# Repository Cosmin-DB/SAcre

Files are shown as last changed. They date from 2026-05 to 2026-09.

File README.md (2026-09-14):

# SAcre / SmartFeedbackDevice

Diseño electrónico de un dispositivo portátil basado en ESP32.

- Autor: Cosmin Dobrescu
- Herramienta: KiCad 10
- Proyecto principal: `sacre.kicad_pro`
- Estado: esquema y PCB corregidos; revisión digital completada (2026-09-13).
  Pendientes: aprobación física final, preparación del pedido y pruebas del prototipo.

## Mecanismo de trabajo

1. Leer este archivo completo antes de continuar una revisión.
2. Usar este README como única fuente de verdad. Las hipótesis nuevas del
   asistente se mantienen únicamente en `REVISION_PROVISIONAL.md` hasta que el
   autor las acepte o descarte; no crear otros informes auxiliares.
3. Mantener un identificador estable para cada incidencia.
4. Tratar toda incidencia inicialmente como una hipótesis, no como un fallo
   confirmado.
5. Intentar refutarla contrastando esquemático, PCB, símbolo, huella, datasheet
   y, cuando exista, evidencia del prototipo.
6. Registrar únicamente:
   - `Hipótesis`: afirmación que se comprueba.
   - `Evidencia`: datos concretos que sostienen el dictamen.
   - `Acción`: cambio exacto, solo si procede.
   - `Cierre`: comprobación necesaria para darlo por válido.
7. Usar estos estados:
   `PENDIENTE → CONFIRMADO / DESCARTADO / CONDICIONAL → CORREGIDO → VALIDADO`.
8. Durante la verificación no modificar el diseño.
9. La preparación de PCB autorizada el 2026-09-13 ya se completó. El enrutado
   y ajuste físico quedan al autor; cualquier nueva modificación de PCB por
   el asistente requiere un alcance autorizado. Comparar antes/después y no
   alterar cobre, contorno, conectores o keepout fuera de ese alcance.
10. Registrar por separado en cada incidencia:
    - `[ ] Esquemático corregido`
    - `[ ] PCB corregida y revisada por el autor`
11. Corregir únicamente incidencias `CONFIRMADO`; no corregir las
    `CONDICIONAL` sin resolver antes su condición.
12. Marcar `VALIDADO` solo después de aplicar el criterio de cierre y las
    comprobaciones ERC/DRC pertinentes.
13. Mantener separadas las mejoras preventivas de los fallos demostrados.
14. Evitar duplicar información y conservar las entradas breves, verificables
    y comprensibles sin contexto externo.
15. No volver a listar como trabajo pendiente una corrección ya aplicada.
    Distinguir revisión digital, aprobación del autor y prueba física; los
    datos de versiones antiguas deben identificarse como históricos.

## Fuentes para la verificación

Los datasheets recopilados están en `documentation/datasheets/`; se conservan
también los documentos útiles que ya estaban en `documentation/` y `RV-8803/`.
`bom_jlcpb.csv` identifica las piezas del prototipo anterior: sirve para
investigar sus fallos, no para pedir la nueva placa. Para fabricar, generar
el BOM desde el diseño actual usando sus campos `LCSC Part #`; ni los BOM
históricos ni las tablas resumidas de este documento sustituyen esa exportación.

| Bloque | Referencias cubiertas | Estado |
| --- | --- | --- |
| MCU y RF | ESP32-PICO-D4, guía de hardware ESP32, AN012400C00R3200 | Completo |
| Pantalla y táctil | GDEY042T81-T02, SSD1683, FT6336U, AFC24-S06FIC-00, AFC24-S24FIA-00 | Completo |
| USB, sensores y mando | CP2104, conector USB-C, LIS3DH, RV-8803-C7, pulsador | Completo |
| Alimentación y protección | TLV62568, TP4054, FHD4020S-470MT, FTC252012S1R0MBCA, BAT54C, MBR0530, SP0503BAHTG | Completo |
| Transistores y motor | CJ2312, CJ3415, SI1308EDL, UMH3N, S8050 | Completo para los componentes montados |

Selección actual de referencias críticas (incluye las sustituciones del prototipo):

| Ref. | Pieza seleccionada | LCSC |
| --- | --- | --- |
| Q2 | R+O S8050 | C20069125 |
| U5 | JSMSEMI TP4054 | C5381776 |
| L1 | cjiang FHD4020S-470MT | C843300 |
| L3 | cjiang FTC252012S1R0MBCA | C5832370 |
| Q4 | TECH PUBLIC SI1308EDL | C7603347 |
| D1, D8, D9 | JSCJ MBR0530 | C77336 |
| D2–D4 | onsemi MBR0530T3G | C236079 |
| D5 | R+O BAT54C | C22466350 |

Los documentos de MCP73831 y LQH44PN quedan solo como comparación: no
describen los componentes seleccionados para la nueva fabricación.

Auditoría de campos de compra: **85 componentes, 39 códigos distintos** con
`LCSC Part #` idéntico en esquema y PCB, incluida R28=`C21190` como R11.
No se añaden alias duplicados: Fabrication Toolkit, instalado en este equipo,
lee ese campo y lo exporta junto a `Designator`, `Footprint`, `Quantity` y
`Value`. Sincronizar esquema y PCB antes de exportar; comprobar códigos y
orientaciones en la previsualización de JLCPCB, no sólo la detección automática.
Chequeo del exportador y propuestas no aplicadas de reducción de variedad:
`REVISION_PROVISIONAL.md`, sección «BOM y posiciones de montaje» (2026-09-14).
Fuentes: [atributos del exportador](https://github.com/bennymeg/Fabrication-Toolkit#attributes)
y [guía KiCad de JLCPCB](https://jlcpcb.com/help/article/how-to-generate-the-bom-and-centroid-file-from-kicad).

H1–H4, J5, J6 y TP1 son elementos de PCB, sin referencia de compra y excluidos
del BOM. M1 se compra por AliExpress: excluido del BOM y del archivo de
posiciones de montaje en esquema y PCB; su huella y conexiones se conservan.
Quedan por confirmar modelo, corriente de arranque y encaje del motor.

Preparación del pedido (2026-09-14): JLCPCB emparejó correctamente las 85
referencias con los 39 códigos previstos para **4 placas ensambladas**. U2,
ESP32-PICO-D4 `C193707`, está clasificado como `Standard Only`, por lo que el
pedido debe usar **Standard PCBA, cara superior**. La propuesta de sustituir
R23/R24 por valores ya presentes reduciría dos alimentadores, pero fue
descartada por el autor: se conservan 24 kΩ/47 kΩ y 39 códigos. En la
previsualización, el autor corrigió manualmente sólo la orientación de Y1;
comprobarla otra vez en cualquier pedido futuro.

Stock consultado en la biblioteca de montaje JLCPCB el 2026-09-13:
39 referencias con existencias. AE1 tenía 8 unidades, pero el autor dispone
de acopio propio; Y1 tenía 2 y se acepta omitir el RTC si falta. SW1 tenía
970 unidades, cantidad aceptada por el autor. Reconfirmar disponibilidad al
pedir: la consulta no reserva piezas ni el stock de LCSC garantiza montaje
inmediato en JLCPCB. Preparar el pedido teniendo en cuenta el acopio y las
omisiones acordadas; no se ha cambiado ningún campo DNP del diseño.

## Fallos observados en el prototipo

Las correcciones indicadas ya están aplicadas al esquema y a la PCB.
Las casillas de aprobación del autor y las pruebas físicas siguen abiertas;
no significan que falte repetir el enrutado. La evidencia del fallo describe
la primera placa fabricada, no la versión actual.

- [ ] `TOUCH-01` SDA y SCL intercambiadas en el FPC táctil.
  - [x] Esquemático corregido: J1.1=`SCL` y J1.2=`SDA`.
  - [ ] PCB corregida y revisada por el autor.
  - `Estado`: CORREGIDO EN ESQUEMA Y PCB; prueba del táctil pendiente.
  - `Cierre`: comprobar detección del FT6336U y niveles/flancos de ambas
    señales con el flex conectado.
- [ ] `TOUCH-02` Revisar holgura, orientación y salida del flex táctil.
- [ ] `MOTOR-01` Incompatibilidad entre el pinout de Q2 y su huella.
  - [x] Esquemático corregido: Q2 es el S8050 SOT-23 montado, B1/E2/C3
    (`C20069125`).
  - [ ] PCB corregida y revisada por el autor.
  - `Estado`: CORREGIDO EN ESQUEMA Y PCB; validación del motor pendiente.
- [x] `TOUCH-03` Pull-up de la interrupción táctil descartado.
  - `Estado`: DESCARTADO; `INT_TOUCH` puede permanecer en GPIO35.
  - `Evidencia`: el FT6336U declara `INT` como E/S CMOS y no prescribe un
    pull-up externo. Verificar por medida sólo si aparecen flancos inestables.
- [ ] `PWR-02` El USB provoca arranque y ciclos rápidos de encendido/apagado.
  - `Estado`: CORREGIDO EN ESQUEMA Y PCB; validación del encendido pendiente.
  - `Hipótesis`: en el diseño fabricado U3 queda alimentado directamente por
    `USB_VBUS` mientras U2 está apagado. `TXD` llega sin aislamiento a `U0RXD`
    y `DTR/RTS` cruzan
    también hacia `EN/GPIO0` mediante Q7; cualquiera de esas vías puede
    realimentar parcialmente el ESP32 y `+3V3`. Esa tensión puede activar
    IO25/Q6 y el latch. Al caer de nuevo la alimentación, el USB repite el
    proceso.
  - `Evidencia`: en el diseño fabricado U3 está configurado como bus-powered;
    `TXD` y `U0RXD` están unidos directamente. Q7 contiene resistencias de base
    internas de 4,7 kΩ,
    pero no aísla un dominio alimentado de otro apagado. IO25 controla la
    puerta de Q6 mediante R18, Q6 tiene un umbral de 0,45–1 V y R14 sólo lo
    descarga con 100 kΩ. R13/C18 forman una constante de 30 ms. L2 puede
    agravar la caída, pero no explica el disparo inicial desde USB.
  - `Decisión`: U3 queda self-powered físicamente. `VDD`, `VIO` y `REGIN` van
    a `+3V3`; R23/R24=24 kΩ/47 kΩ detectan `USB_VBUS` sin realimentación;
    C23=1 µF y C20=0,1 µF desacoplan U3. C17=1 µF mejora `EN`.
    R13/C18 permanecen en 300 kΩ/100 nF; no se añade supervisor ni histéresis.
    El firmware debe activar IO25 pronto y puede exigir mantener el pulsador
    durante la programación.
  - `Cierre`: al conectar USB con el latch apagado, observar `VSYS`, `+3V3`,
    puerta de Q6 y puerta de Q5. Si `+3V3` sube antes que `VSYS`, queda
    confirmada la realimentación desde U3; repetir aislando `TXD` o forzando
    la puerta de Q6 a GND.
  - `Fuentes`: [CP2104, figura 9](documentation/cp2104-1397921.pdf),
    [ESP32-PICO-D4](documentation/datasheets/ESP32-PICO-series.pdf),
    [CJ2312](documentation/datasheets/CJ2312.pdf) y
    [circuito de referencia](https://circuitcellar.com/resources/quickbits/soft-latching-power-circuits/).
  - [x] Esquemático corregido.
  - [ ] PCB corregida y revisada por el autor.
- [ ] `MCU-01` Desacoplo externo local insuficiente en U2.
  - `Estado`: CORREGIDO EN ESQUEMA Y PCB; validación con radio/táctil pendiente.
  - `Hipótesis`: U2 depende de condensadores de `+3V3` alejados y carece del
    par externo recomendado junto al encapsulado.
  - `Evidencia`: el ESP32-PICO-D4 une a `VDD33` los pines 1 `VDDA`, 3 y 4
    `VDDA3P3`, 19 `VDD3P3_RTC` y 37 `VDD3P3_CPU`; su referencia añade
    10 µF + 0,1 µF externos. En la PCB, C17 es de `EN`; C22 está junto al
    regulador y C3/C4 desacoplan el LIS3DH. El SiP incorpora desacoplo interno,
    pero no elimina ese par externo.
  - `Acción`: añadidos C26=10 µF y C27=0,1 µF entre `+3V3` y GND, colocados
    junto al grupo 1/3/4 de U2. Conexión corta y ancha a U2.3/4, con vía GND
    a unos 1 mm del centro de C27.2. Los
    pines 19 y 37 deben quedar unidos por un plano o recorrido de baja
    impedancia; no se prescriben condensadores adicionales junto a ellos
    porque el PICO-D4 ya integra 0,1 µF en ambos dominios.
  - `Cierre`: comprobar colocación y retornos en PCB y medir `+3V3` junto a U2
    con Bluetooth y táctil simultáneos, sin caída por debajo de 3,0 V ni
    brownout.
  - `Fuente`: [ESP32-PICO-D4, figuras 7 y 10](documentation/datasheets/ESP32-PICO-series.pdf).
  - [x] Esquemático corregido.
  - [ ] PCB corregida y revisada por el autor.

## Correcciones aplicadas por bloques

Esquemático sincronizado y PCB enrutada por el autor. Las tareas abiertas
de estos bloques son de firmware o validación física, salvo indicación expresa.

### 1. GPIO, reset táctil y RTC

- [x] `RES_TOUCH_CTRL` en GPIO4; GPIO16 queda sin conexión externa, reservado
  para la flash interna del PICO-D4. JP1 eliminado. R11 y R28, ambas de 1 kΩ
  (`C21190`), están en paralelo: 500 Ω efectivos entre GPIO4 y RSTN.
  Mejora preventiva del nivel bajo sin añadir otra referencia al BOM;
  omitiendo R28 se recupera 1 kΩ. Ambas están previstas para montar.
  C25=10 µF a GND y D8 descarga el nodo al caer `+3V3`. Firmware:
  GPIO4 en drenador abierto, nivel bajo ≥60 ms, liberar sin conducir nivel alto
  y esperar ≥300 ms antes de usar I²C.
- [ ] Validar en prototipo el reset: nivel bajo calculado ≈0,47 V a 3,3 V
  con R11/R28, por debajo de 0,3·IOVCC. Mejora aplicada en esquema y PCB;
  prueba física pendiente. La secuencia de firmware no cambia.
- [x] `ACC_INT2` movida de GPIO12 a GPIO34; se conservan ambas interrupciones.
- [x] `RTC_INT` permanece en GPIO27 con R22=10 kΩ a `+3V3`.
- [x] `RTC_EVI` desconectada de GPIO15, R21=100 kΩ a `VBAT_RAW` y TP1.
- [x] Etiqueta huérfana `GPO` eliminada; GPIO32 queda libre.
- [x] Y1 alimentado directamente por `VBAT_RAW`, sin regulador añadido;
  C2=0,1 µF como desacoplo local.

- [x] Esquemático corregido.
- [ ] PCB corregida y revisada por el autor.

La aprobación final de encaje mecánico corresponde al autor.

### 2. USB, latch, C18 y EN

- [x] U3 alimentado desde `+3V3`; `USB_VBUS` detectado mediante
  R23/R24=24 kΩ/47 kΩ.
- [x] C23=1 µF y C20=0,1 µF locales; C24=4,7 µF/25 V en `VPP`.
- [x] C17=1 µF con R12=10 kΩ en `EN`.
- [x] R13/C18 conservados en 300 kΩ/100 nF; supervisor e histéresis descartados.
- [ ] Firmware integrado: activar IO25 pronto; mantener pulsado durante programación si
  el reset hace caer el latch. Requisito anotado junto al circuito del latch.
  Autosostén implementado en los ocho miniproyectos de `firmware/`;
  integración y prueba física pendientes.
- [x] Esquemático corregido.
- [ ] PCB corregida y revisada por el autor.

### 3. Regulador, ESP32, pantalla y motor

- [x] Pull-ups I²C R7/R8 cambiados de 10 kΩ a 5,1 kΩ para dar margen a
  400 kHz reutilizando el valor existente en el BOM.
- [x] ADP2108 sustituido por U6=`TLV62568DBVR` (`C163219`): buck de 1 A,
  salida nominal de 3,318 V con R26/R27=453 kΩ/100 kΩ. C31/C32=10 µF.
  Se elige por margen de corriente, disponibilidad y coste; el menor consumo
  en reposo y la salida fija del ADP2108 no justifican mantenerlo aquí.
- [x] `L3` fijada como
  [`FTC252012S1R0MBCA`](https://jlcpcb.com/partdetail/FTC252012S1R0MBCA/C5832370),
  LCSC `C5832370`: 1 µH, 4 A, Isat 5,6 A y DCR 35 mΩ. Huella de esquema
  `L_Changjiang_FTC252012S`; `C1042` queda solo como pieza histórica no válida.
  El campo `LCSC Part #` permite su selección automática en el BOM de JLCPCB.
- [x] C26=10 µF y C27=0,1 µF añadidos junto a U2 en el esquemático.
- [x] C26/C27 colocados y retornos revisados; C30 dispone de vía GND local.
- [x] Booster SSD1683 corregido en esquema: L1=47 µH, R10=2,2 Ω;
  C6 permanece en 4,7 µF/25 V; C8/C16 eliminados.
- [x] `L1` fijada como
  [`FHD4020S-470MT`](https://jlcpcb.com/partdetail/FHD4020S-470MT/C843300),
  LCSC `C843300`: 47 µH, 660 mA, Isat 1,3 A y DCR 950 mΩ. Huella de esquema
  `L_Changjiang_FNR4020S`. El campo `LCSC Part #` permite su selección
  automática en el BOM de JLCPCB.
- [x] Booster actualizado y revisado en PCB; Q4.2–R10.2 reducido a 2,34 mm.
  R9=1 MΩ entre GDR y GND, según la aplicación específica del panel.
- [x] Q2 corregido en esquema al pinout real B1/E2/C3 del S8050
  `C20069125`; se conservan R2=1 kΩ y D1.
- [x] Motor pasado de `+3V3` a `VSYS` mediante D9=MBR0530; `VMOTOR` alimenta
  M1, D1 y C1=0,1 µF. R25=100 kΩ mantiene la base de Q2 descargada. PWM
  opcional; encendido/apagado directo condicionado al motor indicado abajo.
- [x] Etapa dimensionada provisionalmente para el motor candidato: 3 V,
  rango 2,5–4 V y 70 mA nominales, suponiendo 90 mA de arranque. Confirmar
  este último dato en el motor comprado; no equivale a validación física.
- [ ] Confirmar modelo comprado, dimensiones/huella y corriente de arranque:
  no dar por corregido a 90 mA el dato ambiguo de 901 mA del anuncio.

### 4. Cargador y batería

- [x] C29=1 µF entre U5.4 `VDD` y GND y C28=10 µF entre U5.3 `VBAT` y
  GND añadidos y colocados junto a U5; retornos locales revisados en PCB.
- [x] R19=5,1 kΩ: unos 196 mA para la batería prevista de 600–700 mAh;
  reutiliza el mismo valor que R16/R17.
- [x] Protección integrada en la batería confirmada por el autor.
- [ ] Firmware integrado: habilitar la medida con GPIO26, leer `ADC_BATT`, deshabilitarla
  y apagar antes de ciclos repetidos de brownout. Requisito anotado en esquema;
  lectura implementada en `firmware/07_bateria`; umbral pendiente de medida.
- [x] Power-path descartado. U5 carga directamente `VBAT_RAW`; carga normal con
  el equipo apagado y encendido temporal permitido para programación.
- [x] Mantener TP4054 `C5381776`: LCSC/JLCPCB lo especifican a 4,2 V. La tabla
  ambigua del datasheet se conserva como cautela de validación, no como fallo
  que obligue a cambiar U5.

### 5. PCB y mecánica

Estado: **ENRUTADA Y REVISADA DIGITALMENTE** (2026-09-13), 93 componentes,
incluida R28 añadida y enrutada por el autor.

- [x] Sincronización, colocación y enrutado de las correcciones; revisión de
  desacoplos, retornos, GPIO y pinout de Q2. DRC sin conexiones pendientes.
- [x] Pista RF ajustada, J3 corregido a NPTH y vías separadas de la ranura.
- [x] Q4–R10 compactado; pasta bajo U2 conservada por decisión del autor.
  D6 no se mueve por la faja; U6 y SW1 se conservan según lo acordado.
- [ ] Comprobar físicamente flex de J1/pantalla, batería, motor y carcasa.
- [ ] Aprobar la PCB y preparar el pedido; ensayar el nuevo prototipo.

Histórico, no estado actual: `ae7a2bc` antes de preparar la PCB;
`92a95f1` colocación provisional; `0903610` enrutado y revisión final.
Las vistas [anterior](documentation/pcb_preparacion/antes.png),
[provisional](documentation/pcb_preparacion/despues.png) y de
[colocación](documentation/pcb_preparacion/colocacion.png) documentan sólo
la preparación inicial; no sirven como referencia de fabricación actual.

## Fabricación y cierre

### Configuración de fabricación — 2026-09-14

Enrutado completado por el autor y revisión digital final realizada.
La configuración de fabricación no cambia la geometría del circuito.

- Pedido objetivo: FR-4 estándar TG135, **4 capas, 1 mm nominal**, cobre
  exterior **1 oz** e interior **0,5 oz**, verde, serigrafía blanca, HASL con
  plomo y fresado normal. Sin prestaciones especiales añadidas.
- Montaje objetivo: **4 unidades, Standard PCBA, sólo cara superior**. U2
  `C193707` impide Economic PCBA. Confirmar el archivo de producción antes de
  fabricar; AE1 y Y1 se seleccionaron desde `My Parts` en el emparejamiento.
- Apilado: **JLC04101H-7628**. La consulta pública de JLCPCB para esos
  parámetros devuelve esta estructura tanto en «No requirement» como al
  seleccionarla explícitamente, con `fixedFee=0`, `coefficient=0` y fabricación
  rápida habilitada. Confirmar precio final en el pedido; no se ha comprado nada.
- KiCad conserva estos parámetros también en las variables de texto del
  proyecto. Elegir el apilado explícito en el pedido para evitar ambigüedad.

| Capa | Espesor configurado | Material / εr de referencia |
| --- | --- | --- |
| F.Mask / B.Mask | 0,0152 mm cada una | Verde / 3,8 |
| F.Cu / B.Cu | 0,035 mm cada una | Cobre exterior 1 oz |
| Dieléctrico 1 / 3 | 0,2104 mm cada uno | FR4 7628 / 4,4 |
| In1.Cu / In2.Cu | 0,0152 mm cada una | Cobre interior 0,5 oz, tras procesado |
| Dieléctrico 2 | 0,5000 mm | Núcleo FR4 / 4,6 nominal |

La estructura publicada suma 1,0212 mm sin máscara; con la máscara modelada,
KiCad muestra **1,0516 mm**. Se pide **1,0 mm nominal**, tolerancia estándar
±10 %. No ajustar artificialmente los dieléctricos para que la suma dé 1,000.

**Límite del modelo RF:** εr son referencias publicadas, no caracterización
del lote TG135. La calculadora actual de JLC usa NP-155F para 4–8 capas y
40,64 µm de cobre exterior, frente a los 35 µm de su tabla de apilado. El
cálculo de la pista RF indicado abajo utiliza el modelo de fabricación de
JLC; no se ha cambiado a TG155 ni simulado la antena completa. `tanδ=0,02`
se conserva como valor orientativo, no como dato confirmado del laminado.

DRC configurado: pista/separación absolutas ≥0,10 mm, cobre–borde ≥0,20 mm,
taladro de vía ≥0,20 mm, diámetro ≥0,40 mm y anular ≥0,05 mm. La regla de
`sacre.kicad_dru` exige diámetro ≥0,45 mm si el taladro es <0,30 mm para
evitar recargo por vías pequeñas. Se mantienen las separaciones de red de
0,15 mm y vías preferidas de 0,50/0,30 mm.
Apertura de máscara–cobre ajeno ≥0,09 mm; texto ≥1 mm y trazo ≥0,15 mm.
No se han cambiado las aperturas de máscara ni las exclusiones existentes.
Los límites específicos de ranuras, PTH y procesos no quedan todos cubiertos
por estas reglas globales: ver las condiciones de fabricación en
`REVISION_PROVISIONAL.md`.

**Resultado:** 0 conexiones pendientes, 0 diferencias con el esquema;
0 infracciones no excluidas y 18 exclusiones previas tras corregir J3 y
adaptar el límite de las vías pequeñas. Los tres errores de
cobre–ranura y los dos avisos de serigrafía fueron corregidos por el autor.
Límites reaplicados con KiCad cerrado y DRC repetido tras detectar que un
guardado posterior había restaurado las restricciones antiguas del proyecto.
U2.49: el autor conserva las ventanas de pasta y las 16 vías recolocadas.
«Plugged» no garantiza el sellado de vías dentro del pad; se acepta esta
limitación sin añadir relleno epoxi/cobre. Calidad de soldadura pendiente
de validar; no es una recolocación o modificación de pasta pendiente.

Fuentes: [apilados JLCPCB](https://jlcpcb.com/impedance),
[capacidades](https://jlcpcb.com/capabilities/pcb-capabilities),
[modelo de cálculo](https://jlcpcb.com/help/article/user-guide-to-the-jlcpcb-impedance-calculator)
y [tratamiento de vías](https://jlcpcb.com/help/article/pcb-via-covering).

### Pista RF — ajuste autorizado el 2026-09-13 (`RV-11`)

- `/ANT_RF`: ancho **0,26 mm** en sus tres segmentos y dos arcos; recorrido,
  huella de antena, meandro y máscara sin cambios. Zonas rellenadas; separación
  lateral a GND ≈0,1505 mm y plano In1 continuo bajo la pista externa.
- Modelo JLC `CoatedCoplanarWaveguideWithLowerGnd1B`: H=0,2104 mm, εr=4,4,
  cobre acabado=40,64 µm, ancho superior 12,7 µm menor que el inferior;
  máscara εr=3,8, 25,4 µm sobre sustrato y 15,24 µm sobre cobre. Son los
  parámetros actuales del servicio, no todos coinciden con su página de ayuda.
- Resultado nominal con hueco lateral de 0,15 mm: **50,15 Ω** para 0,26 mm,
  frente a 44,87 Ω para el ancho anterior de 0,3341 mm. La aproximación previa
  sin máscara de 50,8 Ω queda sustituida por este contraste más completo.
- Este cálculo no valida la impedancia del lote TG135 ni la adaptación/alcance
  de la antena completa. Recalcular si cambian apilado, cobre, máscara, ancho,
  separación a masa o plano de referencia. Recordatorio junto a AE1 en
  `Cmts.User`, fuera del contorno; no forma parte de la serigrafía.
- [ ] PCB revisada visualmente por el autor; validación RF física pendiente.
- Fuente: [calculadora JLCPCB](https://jlcpcb.com/pcb-impedance-calculator).

### Checklist de cierre

- Revisión final de PCB (2026-09-13): 0 conexiones pendientes, 0 diferencias
  con el esquema y 0 infracciones no excluidas tras ajustar las reglas de vía;
  se mantienen 18 exclusiones previas. Q4–R10 ya corregido; pasta de U2 conservada por
  decisión del autor. Gerber/taladros revisados en `tmp/final-review-fab/`,
  no publicados como fabricación definitiva. Resultado y límites en
  `REVISION_PROVISIONAL.md`, «Cierre de revisión sobre el guardado actual».
- `RV-15`: agujeros de posicionamiento de J3 corregidos a NPTH de 0,70 mm
  en PCB y biblioteca; posiciones y anclajes soldados intactos. DRC sin
  infracciones nuevas por este cambio; revisión visual del autor pendiente.

Las siguientes casillas son el cierre humano o experimental, no correcciones
eléctricas obligatorias abiertas:

- [ ] `PWR-01` Medir alimentación, carga y encendido/apagado sin bucles.
- [ ] `USB-01` Probar enumeración y programación, incluido el autosostén.
- [ ] `MCU-02` Probar arranque/reset y coexistencia de táctil y Bluetooth.
- [ ] `DISP-01` Probar refresco y tensiones auxiliares de la pantalla.
- [ ] `SENS-01` Probar sensores/RTC y calibrar el umbral de batería baja.
- [ ] `RF-01` Validar alcance de radio; el cálculo de pista ya está realizado.
- [ ] `PCB-01` Aprobación visual final del autor; revisión digital completada.
- [ ] `MECH-01` Confirmar encaje, alturas, flex y accesibilidad.
- [ ] `FAB-01` Aprobar exclusiones DRC y avisos ERC, comprobar BOM/posiciones
  y stock del pedido, regenerar/revisar el paquete definitivo y confirmar CAM.
  ERC: 122 desajustes de símbolos y aviso de AE1.2, conectado a GND;
  no se declara limpio ni se actualizan bibliotecas a ciegas.

## Uso

Pruebas independientes para el hardware actual: [firmware/README.md](firmware/README.md).
Ocho proyectos PlatformIO, uno por periférico/función, con autosostén del latch
común. Incluyen mapa GPIO y criterios de prueba; validación física pendiente.

Abrir `sacre.kicad_pro`. Las librerías, huellas y modelos 3D del diseño están
incluidos en el repositorio; el estado de los datasheets figura arriba.

Cualquier exportación local en `production/` debe considerarse desactualizada
hasta completar `FAB-01`.

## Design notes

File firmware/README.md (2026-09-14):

# Pruebas independientes de SAcre

Autor: Cosmin Dobrescu. Destino: ESP32-PICO-D4, esquema/PCB de septiembre
de 2026. Cada carpeta es un proyecto PlatformIO que sustituye al anterior
al grabarlo. No hay una aplicación que combine los periféricos.

`common/board.h` concentra los GPIO, autosostén y apagado; `common/i2c_io.h`
contiene únicamente acceso a registros. Conservar `common/` junto a los
proyectos. Para integrarlos después, reutilizar sus rutinas de inicialización
y lectura, manteniendo un único arranque del latch y del bus I²C.

## Compilar y cargar

Instalar PlatformIO Core o la extensión PlatformIO de VS Code. Abrir la
carpeta de la prueba, o ejecutar desde la raíz del repositorio:

```text
pio run -d firmware/01_latch
pio run -d firmware/01_latch -t upload
pio device monitor -b 115200
```

Cambiar `01_latch` por la prueba elegida. Si hay varios puertos, añadir
`--upload-port COMx` al comando de carga y `-p COMx` al monitor.
Los comandos son letras/números ASCII; Intro es opcional.

Usar batería conectada. Mantener SW1 pulsado durante carga/reset y hasta
el arranque del programa; el USB no sustituye al pulsador de encendido.
En todas las pruebas, `x` apaga: soltar SW1 para que pueda cortar el latch.
Una operación en curso (por ejemplo, refrescar pantalla) termina antes de
atender el comando. Abrir el monitor puede perder el primer mensaje;
las pruebas de lectura siguen mostrando su estado periódicamente.

## Qué probar y qué observar

| Proyecto | Operación | Resultado esperado |
| --- | --- | --- |
| `01_latch` | Soltar SW1 después de arrancar; `x` apaga. `b` habilita lectura del botón; soltar, pulsar 4 s y soltar. | Sigue encendida sin pulsar; contador continuo, sin reinicios; apagado efectivo. |
| `02_pantalla` | `p` patrón, `w` blanco, `n` negro; ≥5 s entre refrescos. | Marco/texto/cuadrícula completos, blanco/negro uniformes. Imagen retenida al apagar. |
| `03_tactil` | Tocar, arrastrar y usar dos dedos; `r` repite reset. | Lecturas 0–2 puntos, coordenadas cambiantes, regreso a 0 al soltar; INT/flancos observables. |
| `04_motor` | `1`, `2`, `3`: pulso de 200 ms a 25 %, 50 %, 100 %; `0` para. | Vibra y se detiene; reposo de 2 s entre órdenes, sin reinicios. A PWM bajo puede no arrancar. |
| `05_acelerometro` | Girar y mover la placa. | Identidad `0x33`; en reposo módulo de aceleración ≈1000 mg; signos/ejes cambian; INT1 datos listos, INT2 al superar ≈1,28 g en algún eje. |
| `06_rtc` | `t` inicializa, `a` alarma al próximo minuto, `c` cancela/limpia. Apagar y volver a encender sin `t`. | Segundos avanzan y hora se conserva con batería; alarma da AF=1 e INT=0, `c` los libera. |
| `07_bateria` | Lectura automática cada 2 s; comparar con multímetro. | Tensión próxima a la batería; divisor se deshabilita tras cada lectura. |
| `08_bluetooth` | Cliente BLE: conectar a `SAcre-BLE-test`, leer/suscribirse y reconectar. | Contador ASCII creciente por lectura/notificación, reconexión y sin reinicios. |

BLE: servicio `b0d80001-6c3a-4d2e-a947-5ac000000001`, característica
`b0d80002-6c3a-4d2e-a947-5ac000000001`. Sin emparejamiento obligatorio;
usar un explorador GATT, no sólo la lista de dispositivos del sistema.

## GPIO contrastados con esquema y PCB

Son números de **GPIO**, no de patilla del encapsulado. Los 17 valores de
`common/board.h` se contrastan con redes de U2 y pads reales de la PCB.

| Función / red | GPIO |
| --- | --- |
| Autosostén `PWR_BTN` | 25 |
| Motor `Vibration_PWM` | 13 |
| Batería `VBAT_SENSE_EN` / `ADC_BATT` | 26 / 33 (ADC1) |
| I²C `SDA` / `SCL` | 21 / 22 |
| Táctil `RES_TOUCH_CTRL` / `INT_TOUCH` | 4 / 35 |
| Acelerómetro `ACC_INT1` / `ACC_INT2` | 14 / 34 |
| RTC `RTC_INT` | 27 |
| Pantalla `SS` / `DC` / `RES` | 5 / 10 / 9 |
| Pantalla `BUSY` / `SCK` / `MOSI` | 19 / 18 / 23 |

GPIO34/35 se usan sólo como entradas, sin pull-up interno. GPIO16 y las
señales internas de flash no se usan. GPIO9/10 sí están disponibles en el
PICO-D4 con esta configuración DIO. `RTC_EVI` no está conectado al ESP32.

## Decisiones que hay que conservar al integrar

- **Latch:** GPIO25 HIGH es la primera acción de `setup()`. Los proyectos de
  periféricos mantienen HIGH continuamente. Sólo `01_latch`, tras `b`, usa
  ventanas de entrada de 200 µs para leer SW1 a través de D5/R18; dependen
  del circuito R13/C18 (~30 ms) y necesitan validación física. No se hereda
  automáticamente esta lectura del botón en el resto de pruebas.
- **Táctil:** GPIO4 open-drain LOW 70 ms, liberar y esperar 350 ms, conforme
  a R11||R28=500 Ω y C25=10 µF. Nunca conducir HIGH en push-pull. Se lee el
  FT6336U en `0x38`, 100 kHz, con transferencias acotadas y errores explícitos.
  Las coordenadas son nativas; no se presupone orientación del flex/pantalla.
- **Acelerómetro:** SA0/SDO tiene pull-up interno según el datasheet, por lo
  que se espera `0x19` aunque no tenga conexión externa. Se comprueban
  `0x18/0x19` y WHO_AM_I antes de escribir. Modo ±2 g, 10 Hz, 12 bits,
  BDU; INT1 indica datos listos e INT2 movimiento por umbral.
- **RTC opcional:** si falta, el programa informa y permite apagar.
  Arrancar no cambia la hora. `t` reinicializa la configuración escribible,
  incluido offset=0, a fecha/hora de **compilación**, no a la hora actual del
  PC al cargar. `V2F`/RESET impiden presentar la hora como válida.
  Cada escritura termina con lectura por la errata I²C del RV-8803;
  no se generan pulsos de recuperación indiscriminados. `a` dedica INT a la
  alarma; se deja AF activo hasta `c`, y puede repetirse al día siguiente
  si se deja armada. La batería mantiene esos registros al apagar el ESP32.
- **Pantalla:** driver específico GDEY042T81/SSD1683, sólo refresco completo,
  hibernación al terminar. El SPI no identifica el panel: fin del driver
  no demuestra imagen correcta; comprobar BUSY y aspecto físico.
- **Motor:** apagado inicial y pulsos sólo por orden. PWM no limita el pico
  de arranque ni protege un motor incompatible. Modelo/corriente del motor
  siguen condicionados a lo anotado en el README de hardware.
- **Batería:** R5/R6=10 kΩ/10 kΩ, factor 2; ADC en mV y atenuación 11 dB.
  Ajustar `CALIBRATION` con multímetro. No inventar porcentaje ni umbral de
  apagado: queda para la integración, tras medir la batería y la caída bajo carga.

## Verificación y fuentes

Verificación 2026-09-14: ocho proyectos compilados y enlazados para `pico32`;
17 GPIO contrastados automáticamente con netlist del esquema y pads de la PCB.
Sin avisos en el código propio; dos avisos de variables sin uso en drivers
ajenos al panel elegido dentro de GxEPD2. No probado en placa:
compilación y contraste de GPIO no validan el funcionamiento físico
ni la coexistencia de periféricos. La integración y pruebas combinadas quedan
para una fase posterior.

Base fijada: PlatformIO espressif32 6.1.0 / Arduino-ESP32 2.0.7, `pico32`,
flash 4 MB DIO. Pantalla: GxEPD2 1.6.4, Adafruit GFX 1.11.11 y BusIO 1.16.1.
El resto usa Arduino/Wire/BLE incluidos en esa plataforma.

Referencias: [diseño y decisiones actuales](../README.md),
[LIS3DH](../documentation/lis3dh_datasheet.pdf),
[RTC: mapa, alarmas e inicialización](../RV-8803/RV-8803-C7_App-Manual.pdf),
[errata RTC](../documentation/datasheets/RV-8803-C7-errata.pdf),
[FT6336U](../documentation/datasheets/FT6336U.pdf),
[panel](../documentation/datasheets/GDEY042T81-T02.pdf),
[driver GxEPD2](https://github.com/ZinggJM/GxEPD2/tree/1.6.4),
[formato de registros táctiles](https://github.com/bitbank2/FT6236G/blob/master/src/FT6236G.cpp).
Se toma como referencia funcional el proyecto local de mayo/junio de 2026
`260527-095526-pico32`; sus pines antiguos no son la referencia de esta versión.

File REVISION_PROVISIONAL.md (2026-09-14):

# Revisión provisional independiente

**Autor:** Cosmin Dobrescu
**Última actualización:** 2026-09-14
**Estado:** revisión digital completada; pruebas del prototipo pendientes.
El README mantiene el checklist vigente y las decisiones aceptadas.

No se repiten aquí los cinco fallos ya anotados en el esquemático.

## BOM y posiciones de montaje — 2026-09-14

Revisión con Fabrication Toolkit instalado, traducción automática activada.
Campos corregidos y documentados; las propuestas siguientes **no se han
aplicado**. No se han cambiado valores, huellas, giros ni pistas en esta pasada.

### BOM-01 — Reducir variedad sin modificar el enrutado

- **Estado: DESCARTADA PARA ESTA REVISIÓN por el autor (2026-09-14).** Se
  evaluó cambiar R23 de 24 kΩ a
  5,1 kΩ (`C23186`) y R24 de 47 kΩ a 10 kΩ (`C25804`), ambas 0603, 1 %.
  Reutiliza dos referencias existentes y elimina `C23352` y `C25819`:
  **39 → 37 códigos**, manteniendo la cantidad de componentes.
- **Evidencia:** el divisor de detección USB pasa de 3,3099 V a 3,3113 V
  con entrada de 5 V. A 5,25 V y tolerancias de 1 % en el peor sentido,
  pasa de 3,4988 V a 3,5002 V, por debajo del límite de 3,6 V con U3 apagado.
  No amplía el rango USB admitido ni protege frente a sobretensiones.
- **Coste eléctrico:** consumo del divisor de 70 a 331 µA mientras hay USB
  (+0,261 mA desde USB, no desde la batería). La resistencia equivalente
  baja de 15,89 a 3,38 kΩ; no empeora el error por fugas de entrada.
- **Justificación:** cálculo propio sobre la figura 9, nota 5 del
  [CP2104](https://www.silabs.com/documents/public/data-sheets/cp2104.pdf),
  que permite un divisor funcionalmente equivalente; 5,1 kΩ/10 kΩ no es
  una pareja prescrita por el fabricante. No se promete ahorro económico
  concreto: la mejora comprobada es reducir variedad.
- **Decisión:** conservar R23=24 kΩ (`C23352`) y R24=47 kΩ (`C25819`). El
  ahorro observado era de unos 2,6 EUR por pedido Standard, insuficiente para
  cambiar una PCB ya terminada. Para diseños futuros, priorizar piezas Basic,
  compatibilidad Economic y reutilización de referencias desde el inicio.

Otros resultados del chequeo:

- **Sólo agrupación:** el exportador produce 41 líneas para 39 códigos porque
  C17/C23/C29 dicen `1uF` y sus equivalentes `1uF/50V`; C30 dice `100nF` y
  sus equivalentes `0.1uF`. Uniformar esos textos reduciría a 39 líneas,
  pero no elimina ninguna referencia de compra; ya comparten código LCSC.
- **Diodos: no unificar de oficio.** D1/D8/D9 y D2–D4 usan dos MBR0530 de
  fabricantes distintos. D9 se eligió para reducir la tensión del motor:
  no basta compartir encapsulado y tensión nominal para asegurar la misma
  caída. Cambiar sólo D1/D8 no reduce variedad porque D9 conserva su código.
- **C18:** su 100 nF es 0402, frente a los demás 0603. Unificarlo exige
  cambiar huella y revisar espacio/pistas; no compensa tocar esta PCB sólo
  por ese motivo. No se propone alterar temporizaciones, feedback o
  componentes de potencia para reutilizar valores a costa de su función.

### FAB-02 — Orientaciones y centros del archivo de posiciones

- **Estado: exportador comprobado y previsualización revisada por el autor.**
  Las 85 referencias del BOM tienen posición, todas en cara superior y sin
  duplicados. El CPL incluye además H1–H4, J5/J6 y TP1, excluidos del BOM:
  son siete entradas sin pieza a montar, no siete componentes sin código.
  M1 queda fuera de ambos archivos por compra/montaje independiente.
- El exportador usa el centro de la caja de pads y el origen auxiliar,
  invirtiendo Y para el CPL. Respecto al ancla de KiCad desplaza el centro
  calculado de J3 0,175 mm a la izquierda, SW1 0,075 mm a la izquierda y
  AE1 0,025 mm a la izquierda/0,030 mm arriba. No demuestra descentrado:
  comprobar el cuerpo sobre sus pads, no igualar coordenadas por intuición.
- Se contrastaron las geometrías numeradas de 26 componentes con bibliotecas
  EasyEDA descargadas por el MCP. **Su cero angular no certifica el cero de
  montaje de JLCPCB.** Q4 no tiene regla SOT-323 en el exportador; Y1 usa
  una huella personalizada; D6 recibe la regla genérica SOT-143 y U2/U3 la
  QFN. Son comprobaciones prioritarias, no giros erróneos demostrados.

Referencia rápida para la previsualización, mirando la PCB por arriba con
la misma orientación que KiCad (X crece a la derecha, Y hacia abajo):

| Pieza | Ángulo CPL actual | Referencia física que debe coincidir con la PCB |
| --- | --- | --- |
| Q4 | 270° | Gate/pad 1 arriba a la derecha; drenador/pad 3 abajo |
| D6 | 270° | Común GND/pad 1 abajo a la izquierda |
| U2 | 270° | Pad 1 en el extremo inferior del lateral derecho |
| U3 | 90° | Pad 1 en el extremo superior del lateral izquierdo |
| Y1, si se monta | 180° | Pad 1 abajo a la derecha |
| D7 | 180° | Cátodo a la derecha, en el pad 1 de KiCad |

En D7 se descartó una falsa alarma de 180° al comprobar el símbolo:
EasyEDA llama **2** al cátodo y KiCad **1**. Comparar sólo los números
habría confundido una convención distinta con un fallo de polaridad.
J1/J2/J3 y SW1 coinciden en orientación de pads con sus huellas importadas;
revisar también la boca del USB y las entradas de los flex en el visor.
No se pudo obtener la huella EasyEDA de AE1: contrastar con su plano y el
componente del acopio al preparar su montaje.

**Resultado de la previsualización (2026-09-14):** el autor encontró correcto
el posicionamiento del resto de componentes y corrigió manualmente únicamente
la orientación de Y1. El ángulo de corrección no quedó registrado, por lo que
todavía no se puede fijar un `FT Rotation Offset` fiable para automatizar Y1
en otro pedido. No se ha girado su huella física ni fijado offsets nuevos.
En futuros pedidos, revisar de nuevo la previsualización con el código exacto
de cada pieza antes de aceptar el montaje.
Los ángulos de esta tabla dependen de mantener activada la traducción
automática de este exportador. No son una tabla para el exportador nativo.
Fuentes: [atributos de Fabrication Toolkit](https://github.com/bennymeg/Fabrication-Toolkit#attributes)
y [guía de corrección de posiciones de JLCPCB](https://github.com/JLCPCB/JLCPCB-SMT-Assembly-Components-orientation-fix).

## Evidencia del prototipo

### OBS-01 — Pantalla funcional; táctil y Bluetooth no coexistían correctamente

**Relato del autor (2026-07-28)**

- El conjunto usado era la pantalla táctil de 4,2 pulgadas declarada en el
  diseño; la pantalla funcionaba.
- El táctil y Bluetooth no funcionaban correctamente al usarlos
  simultáneamente. Falta precisar si ambos funcionaban por separado.

**Separación de bloques**

- La tinta electrónica `GDEY042T81-T02` usa `SSD1683`, conector J2 de 24 pines
  y SPI. El booster sólo interviene al generar las tensiones de refresco.
- El táctil `FT6336U` usa el conector J1 de 6 pines, bus I²C y `+3V3`. Su
  consumo activo típico es 4,32 mA.
- Bluetooth es interno al ESP32 y no comparte los GPIO del I²C. No aparece un
  conflicto directo de pines entre ambas funciones.
- Táctil, ESP32 y booster reciben energía de la misma red `+3V3`.

**Fuentes:** [esquemático](sacre.kicad_sch), [panel](documentation/datasheets/GDEY042T81-T02.pdf), [FT6336U](documentation/datasheets/FT6336U.pdf), [ESP32-PICO](documentation/datasheets/ESP32-PICO-series.pdf).

**Interpretación provisional**

- `TOUCH-01` —SDA y SCL intercambiadas en el FPC— explica un fallo directo del
  táctil, pero no un fallo propio de Bluetooth.
- `RV-05` es ahora la causa lógica más fuerte del táctil si JP1 estaba cerrado:
  su reset comparte por error el `FLASH_CS` interno del ESP32.
- `RV-01` es una causa común plausible: la actividad de radio eleva la demanda
  del ESP32 y una caída de `+3V3` puede reiniciar o bloquear tanto el MCU como
  el FT6336U.
- `RV-02` sólo explicaría la coincidencia si se estaba refrescando la pantalla:
  el booster toma pulsos de corriente de `+3V3`.
- Siguen abiertas causas de firmware, concurrencia y desacoplo local del ESP32.

**Comprobación necesaria**

- [ ] Registrar qué funcionaba por separado: táctil, Bluetooth y refresco.
- [ ] Repetir una matriz táctil activo/inactivo × Bluetooth activo/inactivo,
      sin refrescar la pantalla.
- [ ] Repetir durante un refresco y medir mínimo/rizado de `+3V3`.
- [ ] Registrar brownouts, resets, errores I²C y desconexiones Bluetooth.

## Antecedentes del prototipo y correcciones RV-01–RV-10

Las descripciones de fallos siguientes corresponden al diseño anterior.
Las correcciones indicadas en esquema ya se trasladaron a la PCB y se
revisaron digitalmente; las comprobaciones físicas no se dan por superadas.
RV-08 es una decisión aceptada, no una propuesta de rediseño pendiente.

### RV-01 — L2 no es apta para el regulador de 3,3 V

**Confianza:** muy alta · **Impacto posible:** crítico

- El BOM fabricado monta en L2 `C1042`, identificado como `SDFL2012Q1R0KTF`.
- Su datasheet especifica `Ir = 50 mA` y `DCR = 0,4 Ω`.
- U4 es un ADP2108 de hasta 600 mA. Su datasheet exige que la corriente DC admisible de la bobina sea mayor que la corriente de pico; sus referencias de 1 µH parten de 800 mA.
- L2 alimenta toda la red `+3V3`, incluido el ESP32. Es una incompatibilidad objetiva aunque la placa llegue a arrancar.
- Espressif especifica una fuente capaz de entregar al menos 0,5 A al
  ESP32-PICO. La corriente nominal de L2 es diez veces menor incluso antes de
  sumar pantalla, táctil, sensores y motor.

**Implicaciones**

- `50 mA` no es un corte: L2 puede conducir más corriente, pero fuera de su
  especificación puede perder inductancia, calentarse y elevar el rizado.
- Los síntomas esperables son brownouts o resets del ESP32, fallos de radio,
  periféricos inestables y comportamiento dependiente de batería, temperatura
  o unidad fabricada.
- Es una explicación plausible para la parte Bluetooth de `OBS-01`, no una
  causalidad demostrada.

**Corrección aplicada en el esquemático**

- El conjunto U4/L2 fue sustituido por U6=`TLV62568DBVR` y
  L3=`FTC252012S1R0MBCA`, LCSC `C5832370`: 1 µH, 4 A, Isat 5,6 A y
  DCR 35 mΩ, huella `L_Changjiang_FTC252012S`. Aplicado también en PCB.

**Fuentes:** [BOM fabricado](bom_jlcpb.csv), [L2 C1042, pág. 4](documentation/datasheets/SDFL2012Q1R0KTF-C1042.pdf), [ADP2108, pág. 13](documentation/datasheets/ADP2108.pdf), [ESP32-PICO, tabla 17](documentation/datasheets/ESP32-PICO-series.pdf).

**Comprobación en la placa**

- [ ] Confirmar que la unidad ensayada corresponde al BOM con `C1042`.
- [ ] Registrar mínimo y rizado de `+3V3` durante arranque, radio activa y refresco de pantalla.
- [ ] Decisión: confirmar / descartar / condicionar.

### RV-02 — Booster de la pantalla configurado como UC, pero el panel usa SSD1683

**Confianza:** muy alta sobre la incompatibilidad; causalidad no demostrada · **Impacto posible:** alto, crítico si impide el refresco

- El diseño y el BOM usan `L1 = 10 µH` y `R10 = 0,47 Ω`.
- El panel declarado `GDEY042T81-T02` usa controlador `SSD1683`.
- La guía vigente de Good Display para DESPI-C02 asigna `10 µH + 0,47 Ω` a controladores UC y `47 µH + 2,2 Ω` a controladores SSD. Advierte que una selección incorrecta puede impedir el refresco.
- El esquema oficial DESPI-C02 V1.0 de 2018 usa una bobina fija de 10 µH y
  permite seleccionar `0,47 Ω` o `3 Ω`. La placa conserva precisamente la
  rama de `0,47 Ω`; éste es el origen más probable del valor.
- El circuito de aplicación del SSD1683 confirma `47 µH + 2,2 Ω`. La
  documentación posterior aclara que los valores antiguos no son universales.

**Funcionamiento e implicaciones**

- El SSD1683 controla Q4 mediante `GDR`. L1 almacena energía y los diodos y
  condensadores generan `PREVGH`, `PREVGL` y `VCOM`.
- `RESE` mide sobre R10 la corriente de Q4. Para una misma tensión de control,
  `0,47 Ω` permite unas 4,7 veces más corriente que `2,2 Ω`; con 10 µH la
  corriente también crece unas 4,7 veces más rápido que con 47 µH.
- Esto no implica 4,7 veces más tensión de salida: implica un lazo de corriente
  distinto y mayor esfuerzo durante el arranque del booster.
- Puede causar ausencia o degradación del refresco, poco contraste, ghosting,
  calentamiento y picos sobre `+3V3`. También puede funcionar por tolerancias y
  regulación interna, como ocurrió en el prototipo, sin validar sus márgenes.
- El funcionamiento observado de la pantalla reduce la probabilidad de un
  fallo inmediato, pero no refuta la incompatibilidad ni descarta estrés.

**Alcance revisado**

- Q4 `SI1308EDL` y los Schottky `MBR0530` coinciden con la recomendación
  actual.
- El mapeo completo del FPC confirma su orientación inversa respecto a J2.
  El circuito específico del panel GDEY042T81-T02 resuelve la diferencia entre
  el circuito genérico del SSD1683 y esta aplicación:
  - C6=4,7 µF/25 V coincide con el circuito de referencia del panel y se
    conserva; el valor genérico de 1 µF no prevalece sobre la aplicación
    específica.
  - C8 cargaba con 1 µF J2.21, correspondiente al pin 4 del panel, declarado
    `NC / keep open`.
  - C16 cargaba con 1 µF J2.6, correspondiente al pin 19 `VPP`, declarado
    `FOR TEST` y dejado abierto en el circuito de referencia del panel.
- El táctil FT6336U es un bloque I²C independiente. El booster no explica por sí
  solo su fallo salvo por una caída compartida de `+3V3`.

**Corrección aplicada en el esquemático**

- `L1 = 47 µH` y `R10 = 2,2 Ω`. L1 queda como `FHD4020S-470MT`, LCSC
  `C843300`: 660 mA, Isat 1,3 A y DCR 950 mΩ, con huella
  `L_Changjiang_FNR4020S` en el esquema.
- C6 se conserva en 4,7 µF/25 V; C8 y C16 se eliminan.
- Aplicado también en PCB; el retorno Q4–R10 está compactado (`RV-13`).

**Fuentes:** [BOM fabricado](bom_jlcpb.csv), [panel GDEY042T81-T02](documentation/datasheets/GDEY042T81-T02.pdf), [SSD1683, circuito de aplicación pág. 46](documentation/datasheets/SSD1683.pdf), [producto oficial: IC SSD1683](https://www.good-display.com/product/473.html), [DESPI-C02 V1.0 de 2018](https://v4.cecdn.yun300.cn/100001_1909185148/DESPI-C02_SCH%20V1.0.pdf), [guía oficial DESPI-C02, secciones 3.1 y 4.1–4.4](https://www.good-display.com/companyfile/29.html).

**Comprobación en la placa**

- [ ] Confirmar referencia/revisión del panel realmente probado.
- [ ] Precisar si «funcionaba» incluía refrescos completos y repetibles.
- [ ] Medir `PREVGH`, `PREVGL`, `VCOM` y `+3V3` durante un refresco.
- [ ] Decisión: confirmar / descartar / condicionar.

### RV-03 — Falta el pull-up de `RTC_INT`

**Confianza:** muy alta · **Impacto posible:** alarma/temporizador RTC inoperante o inestable

- `RTC_INT` conecta únicamente `Y1.6` con `U2.IO27`; no hay resistencia de pull-up.
- La salida `INT` del RV-8803-C7 es open-drain y el fabricante indica expresamente que requiere pull-up.
- Un pull-up interno habilitado por firmware puede ocultar el fallo durante algunas pruebas, pero no existe durante reset ni está garantizado por el hardware.

**Corrección aplicada en el esquemático**

- R22=10 kΩ entre `RTC_INT` y `+3V3`; Y1.6 permanece en GPIO27.

**Fuentes:** [RV-8803-C7](documentation/datasheets/RV-8803-C7-datasheet.pdf), [manual de aplicación oficial, pág. 64](https://www.microcrystal.com/fileadmin/Media/Products/RTC/App.Manual/RV-8803-C7_App-Manual.pdf).

**Comprobación en la placa**

- [ ] Medir `RTC_INT` en reposo con el GPIO sin pull-up interno.
- [ ] Provocar una alarma/temporizador y comprobar nivel alto estable y flanco bajo.
- [ ] Decisión: confirmar / descartar / condicionar.

### RV-04 — Falta desacoplo en la salida interna del CP2104

**Confianza:** muy alta · **Impacto posible:** enumeración USB o UART intermitente

- Los pines `VDD` y `VIO` de U3 están unidos entre sí, pero esa red no llega a ningún condensador.
- `REGIN/VBUS` sí tiene C20; no sustituye el desacoplo de `VDD/VIO`.
- El circuito bus-powered del fabricante coloca `1–5 µF` y `0,1 µF` entre `VDD` y GND.

**Implicaciones**

- Aunque no se use para alimentar circuitos externos, `VDD` es la salida del
  regulador interno que alimenta al propio CP2104; `VIO` fija su alimentación
  de E/S.
- La omisión puede producir rizado, resets del CP2104, enumeración USB
  intermitente o programación UART poco fiable. No implica un fallo seguro.

**Corrección aplicada en el esquemático**

- U3 queda alimentado desde `+3V3`; C23=1 µF y C20=0,1 µF son sus desacoplos
  locales. `USB_VBUS` se detecta mediante R23/R24 sin alimentar U3.

**Fuente:** [CP2104, figura 8, pág. 17](documentation/cp2104-1397921.pdf).

**Comprobación en la placa**

- [ ] Medir U3 pin 6 (`VDD`) al conectar USB y durante enumeración/tráfico.
- [ ] Registrar fallos de enumeración, resets o rizado.
- [ ] Decisión: confirmar / descartar / condicionar.

### RV-05 — El reset táctil está conectado a `FLASH_CS` interno

**Confianza:** muy alta · **Impacto posible:** crítico

- `U2.IO16`, pin físico 25 del ESP32-PICO-D4, no es un GPIO disponible:
  está conectado internamente a `FLASH_CS`.
- Esa señal sale como `RES_TOUCH` hasta JP1. Con JP1 cerrado, comparte el reset
  del FT6336U y su pull-up R11 de 10 kΩ. La actividad de la flash puede resetear
  el táctil y éste carga una señal interna crítica del ESP32.
- Con JP1 abierto no existe esa carga directa: R11 mantiene alto el reset del
  táctil. Aun así, el FT6336U no recibe su secuencia recomendada de reset bajo
  durante el encendido y queda un stub de PCB conectado a `FLASH_CS`.
- Es una explicación fuerte de `OBS-01` únicamente si la placa ensayada tenía
  JP1 cerrado.

**Corrección aplicada en el esquemático**

- JP1 y la conexión a IO16 se eliminan. `RES_TOUCH_CTRL` pasa a GPIO4 mediante
  R11=1 kΩ, C25=10 µF y D8; el firmware lo maneja en drenador abierto.
  Mejora posterior aplicada por el autor: R28=1 kΩ en paralelo con R11
  reduce la resistencia efectiva a 500 Ω y aumenta el margen del nivel bajo.

**Fuentes:** [ESP32-PICO-D4, tabla de pines](documentation/datasheets/ESP32-PICO-series.pdf), [FT6336U](documentation/datasheets/FT6336U.pdf).

**Dato pendiente**

- [ ] Confirmar si JP1 estaba soldado/cerrado en la unidad probada.
- [ ] Cierre: verificar en esquema y PCB que IO16 queda sin red, pista ni
      componente externo.

### RV-06 — `ACC_INT2` puede forzar el strap de 1,8 V de la flash

**Confianza:** muy alta sobre la conexión · **Impacto condicionado:** crítico

- `LIS3DH.INT2` llega a `GPIO12/MTDI` del ESP32.
- El ESP32 muestrea GPIO12 en cada reset: bajo selecciona 3,3 V para
  `VDD_SDIO`; alto selecciona 1,8 V. La flash interna del PICO-D4 trabaja a
  3,3 V.
- El LIS3DH arranca con INT2 push-pull a nivel bajo, por lo que un encendido en
  frío puede funcionar. Si el firmware deja INT2 alto y se reinicia sólo el
  ESP32 sin cortar `+3V3`, el sensor conserva ese estado durante el muestreo y
  puede provocar brownout o impedir el arranque.

**Corrección aplicada en el esquemático**

- `ACC_INT2` pasa a GPIO34, entrada sin función de strap.
- Cierre: comprobar arranque en frío y reset sólo de `EN` con INT2 activo.

**Fuentes:** [LIS3DH](documentation/lis3dh_datasheet.pdf), [guía de hardware ESP32](documentation/esp32_hardware_design_guidelines_en.pdf).

### RV-07 — Faltan los condensadores locales del TP4054

**Confianza:** muy alta · **Impacto posible:** carga inestable

- La aplicación típica del componente exacto pide 1 µF en su entrada de
  alimentación y 10 µF en la salida de batería, ambos locales a U5. En el
  símbolo del esquema son `VDD` y `VBAT`. Ninguno está presente.
- C2 es 0,1 µF sobre `VBAT_RAW` para el RTC; no sustituye los 10 µF locales de
  U5. C20 y C23 desacoplan `+3V3` en el CP2104, no `USB_VBUS`.

**Corrección aplicada en el esquemático**

- C29=1 µF entre U5.4 (`VDD`) y GND y C28=10 µF entre U5.3 (`VBAT`) y
  GND, colocados junto a U5 con retornos locales revisados en PCB.
- Cierre: comprobar estabilidad en U5.4 y U5.3 durante conexión y carga.

**Fuente:** [TP4054 JSMSEMI, aplicación típica](documentation/datasheets/TP4054-JSMSEMI-C5381776.pdf).

### RV-08 — El cargador no separa la batería de la carga del sistema

**Confianza:** muy alta sobre la topología · **Impacto condicionado:** alto

- U5 conecta `BAT` directamente a `VBAT_RAW`; no existe power-path ni reparto
  de carga.
- Si el equipo permanece encendido mientras carga, el TP4054 mide conjuntamente
  batería y consumo del sistema. La terminación puede retrasarse o no producirse
  y la batería puede aportar los picos que excedan la corriente del cargador.
- R19 se cambia de 10 kΩ a 5,1 kΩ: programa unos 196 mA para la batería prevista
  de 600–700 mAh y reutiliza el valor de R16/R17. La terminación ocurre
  alrededor de C/10, por lo que una carga activa superior a unos 20 mA puede
  impedirla.
- La batería incorpora protección propia, confirmado por el autor.
- El datasheet del TP4054 contiene una tabla ambigua con un límite de 4,28 V y
  grados A/B poco claros. Sin embargo, LCSC y JLCPCB identifican el componente
  exacto `C5381776` como 4,2 V. Se mantiene U5; medir la tensión final forma
  parte de la validación, no de una corrección del esquema.

**Decisión cerrada**

- No añadir power-path. U5 permanece conectado directamente a `VBAT_RAW`.
- Especificar carga normal con el equipo apagado. Mantenerlo encendido
  temporalmente para programar es admisible, aunque no garantiza terminación
  de carga mientras exista consumo.
- Cierre: validar terminación y corriente real con el sistema apagado y, si se
  permite, encendido.

### RV-09 — `RTC_EVI` queda sin nivel definido con el MCU apagado

**Confianza:** muy alta · **Impacto posible:** eventos espurios del RTC

- `Y1.EVI` conecta únicamente con GPIO15. El RV-8803 permanece alimentado desde
  `VBAT_RAW`, mientras el ESP32 y sus polarizaciones desaparecen al apagar el
  latch.
- El fabricante indica que EVI no debe quedar flotante.

**Corrección aplicada en el esquemático**

- `RTC_EVI` se desconecta de GPIO15 y queda inactiva mediante R21=100 kΩ a
  `VBAT_RAW`, con TP1 para un posible uso futuro.
- Cierre: medir un nivel definido en EVI con el latch encendido y apagado.

**Fuente:** [manual RV-8803-C7](RV-8803/RV-8803-C7_App-Manual.pdf).

### RV-10 — El RC de `EN` conserva la recomendación antigua de 100 nF

**Confianza:** muy alta sobre la desviación · **Impacto posible:** arranque menos robusto

- R3 = 10 kΩ y C17 = 100 nF forman el reset de encendido del ESP32.
- La guía vigente de Espressif recomienda 10 kΩ + 1 µF para mejorar la
  estabilidad de encendido.

**Corrección aplicada en el esquemático**

- C17=1 µF con R12=10 kΩ. El arranque será algo más lento y puede exigir
  mantener el pulsador durante más tiempo; no sustituye la corrección de
  `PWR-02`.
- Cierre: comprobar subida limpia de `EN`, arranque manual y reset de
  programación.

**Fuente:** [guía de hardware ESP32](documentation/esp32_hardware_design_guidelines_en.pdf).

## Condiciones abiertas, no clasificadas como fallo

- Pull-ups I²C R7/R8=5,1 kΩ ya aplicados. Usar 100 kHz hasta validar los
  flancos del conjunto PCB/flex; no se garantiza 400 kHz sólo por ese valor.
- **Regulador: selección cerrada.** U6=`TLV62568DBVR` de 1 A sustituye al
  ADP2108; L3 y C31/C32 son los componentes actuales. El motor toma energía
  de `VSYS`. Presupuesto y márgenes en `AUDITORIA_COMPONENTES.md`.
- Con batería baja, verificar el apagado por firmware antes de perder el
  margen de alimentación del ESP32; la protección de batería no sustituye
  ese umbral, pendiente de calibración.
- La medida de batería en ADC1 es válida; añadir 100 nF local sería una mejora
  de filtrado, no un fallo demostrado.
- `MOTOR-01`: Q2 ya está corregido al pinout B1/E2/C3 del S8050 montado
  (`C20069125`). El motor toma energía de `VSYS` mediante D9=MBR0530;
  C1=0,1 µF y R25=100 kΩ. PCB aplicada; dimensionado condicionado al candidato
  de 70 mA nominales y 90 mA de arranque. Quedan referencia de compra,
  corriente real y comprobación mecánica; no se considera ensayado.

## Comprobaciones descartadas

- **D5/BAT54C:** el pin común 3 va al pulsador; D5.1 sí permite descargar la puerta de Q5. La topología de encendido es coherente.
- **LIS3DH:** símbolo, desacoplo, `CS` y `SDO/SA0` son coherentes; `ACC_INT2`
  ya está corregida de GPIO12 a GPIO34 según `RV-06`.
- **ESP32-PICO-D4:** `SD2/GPIO9` y `SD3/GPIO10` no están ocupados por la flash interna de esta variante. El condensador de `VDD_SDIO` mostrado en el esquema interno forma parte del SiP; no se cuenta como componente externo ausente.
- **CP2104:** el pad expuesto central es GND opcional según el fabricante; que
  esté sin conectar no constituye un fallo. El pinout y la función de Q7 son
  correctos.
- **USB-C y RF:** CC1/CC2, protección ESD, pares USB, adaptación integrada del
  PICO-D4 y keepout de antena no muestran otro fallo eléctrico evidente.

## Revisión de enrutado — 2026-09-13

### Cierre de revisión sobre el guardado actual (2026-09-13)

Último contraste de documentación, netlist actual y referencias de fabricante:
sin incompatibilidad grave nueva detectada. DRC repetido con relleno de zonas
en memoria: 0 infracciones activas, 18 exclusiones, 0 conexiones pendientes y
0 diferencias con el esquema. La mejora posterior R11/R28 ya está aplicada
por el autor en esquema y PCB; el asistente completa sólo el campo de compra
de R28 y excluye M1 de BOM/posiciones, sin tocar geometría ni conexiones.
85 componentes tienen código de compra coincidente en esquema y PCB.
Persisten las condiciones del motor y las pruebas del reset descritas en
`AUDITORIA_COMPONENTES.md`; no se considera superada ninguna prueba física.
Corregida en README la selección de D2–D4 a `C236079` y separada del BOM histórico.

Referencia histórica de cobre revisado, anterior a R28 y a la nota RF en `Cmts.User`:
SHA256 `e97267a49af78ba223983d335d8b887f7e7fd721cb2c1a0c7f3eb2a174cb04b4`.
La nota documental no cambia cobre, componentes, taladros ni máscaras.

- **DRC:** 0 conexiones pendientes, 0 diferencias con el esquema y 0 infracciones
  no excluidas tras el ajuste autorizado de reglas. Taladro mínimo de 0,20 mm;
  `sacre.kicad_dru` exige diámetro exterior ≥0,45 mm si el taladro es <0,30 mm.
  Quedan 18 avisos excluidos previos, no 22 tras corregir J3. Prueba aislada:
  admite 0,20/0,45 y 0,30/0,40 mm; rechaza 0,20/0,40 y taladro de 0,15 mm.
  Geometría de PCB intacta.
- **Fabricación:** las 159 vías son pasantes: 135 de 0,30/0,50 mm, 20 de
  0,40/0,80 mm y 4 de 0,20/0,45 mm (taladro/diámetro exterior). Ninguna
  incumple las combinaciones sin recargo por vía pequeña publicadas por JLC.
- **RV-13:** Q4.2–R10.2 corregido por el autor: 2,34 mm a 0,25 mm, sin vías,
  frente a 15,94 mm. R10 retorna al cobre local GND. No queda propuesta de
  recolocación; validar el booster en el prototipo.
- **RV-17:** ahora hay 16 vías bajo U2.49; ningún taladro se solapa con las
  nueve ventanas de pasta. Margen mínimo de las cuatro interiores: 0,020–0,034 mm.
  El autor decide conservar la pasta y asumir este margen; no modificarla
  ni contratar relleno automáticamente. No equivale a soldadura validada.
- **ERC:** 122 avisos de desajuste de símbolos y 1 aviso de pin no alimentado
  en AE1.2. Este pin está modelado como entrada y unido a GND en esquema/PCB;
  no se ha encontrado una desconexión física que justifique cambiar el circuito.
  El ERC no se declara limpio. Las seis huellas con aviso de biblioteca
  conservan numeración, posición, tamaño, forma y taladro de sus pads frente
  a la biblioteca; no se han actualizado indiscriminadamente.
- **Gerber/taladros:** exportados de nuevo a `tmp/final-review-fab/` para
  inspección, con zonas recalculadas en memoria. Revisadas las cuatro capas
  de cobre, máscaras, pasta, serigrafía y contorno con un lector independiente.
  NPTH: cuatro agujeros de 2,70 mm y los dos de J3 de 0,70 mm; cuatro ranuras
  USB permanecen metalizadas. No usar los archivos antiguos de `production/`.
- **Retornos/RF:** In1 y B.Cu mantienen planos GND continuos; pista RF de
  0,26 mm y 14,80 mm con In1 debajo. Desacoplos y bloques USB/regulador/booster
  revisados sin otro fallo concreto detectado. Se conservan las decisiones
  aceptadas sobre D6, U6 y SW1. Encaje físico, EMC/RF y funcionamiento real
  siguen pendientes del autor/prototipo; no los certifica esta revisión.

### RV-11 — Comprobar los 50 Ω de la pista RF con el apilado de fabricación

- **Estado: CORREGIDO EN PCB por autorización del autor; revisión visual y
  validación RF pendientes.** Decisión y parámetros definitivos de este ajuste
  registrados en README, sección «Pista RF».
- **Evidencia:** con JLC04101H-7628, H=0,2104 mm y separación lateral de
  0,15 mm, el servicio JLC con máscara devuelve 44,87 Ω para 0,3341 mm y
  50,15 Ω para 0,26 mm. Es cálculo nominal, no un fallo funcional medido.
  Las aproximaciones anteriores de 33 Ω (apilado antiguo de KiCad) y
  50,8 Ω (modelo simplificado sin máscara) no describen este cálculo final.
- **Acción aplicada:** tres segmentos y dos arcos de `/ANT_RF` pasan a
  0,26 mm; zonas rellenadas. Recorrido de 14,80 mm, huella/meandro y resto
  del diseño conservados. GND lateral ≈0,1505 mm, In1 continuo debajo.
- **Cierre parcial:** DRC sin infracciones no excluidas, sin conexiones
  pendientes ni discrepancias de esquema. El lote
  TG135 y la antena completa siguen necesitando validación física.
- [ ] PCB corregida y revisada por el autor; esquemático sin cambio propuesto.

### RV-12 — Retornos locales de C31/U6 y C30

- **Estado: C31/C30 CORREGIDOS; U6 CONSERVADO.** Mejora preventiva de
  retornos, no fallo funcional demostrado. C31 tiene vía GND a 1,14 mm del
  centro de su pad de masa (antes 4,16 mm), y C30 a 1,62 mm (antes 4,67 mm).
  Ambas conectan al cobre local. U6.2 conserva la vía a 2,48 mm y cobre GND
  continuo; el autor indica que no puede acercarlo más. No queda recolocación
  solicitada ni hay que volver a añadir las vías de C31/C30.
  C26/C27 están razonablemente colocados: conexión ancha y corta a U2.3/4,
  con una vía GND aproximadamente a 1 mm de C27.2.
- **Cierre:** inspección de los retornos con zonas rellenadas y DRC; no atribuir
  a este detalle los reinicios antiguos sin medir. Fuentes:
  [TLV62568, §10](https://www.ti.com/lit/ds/symlink/tlv62568.pdf) y
  [guía ESP32, colocación del desacoplo](documentation/esp32_hardware_design_guidelines_en.pdf).
- [ ] PCB corregida y revisada por el autor; esquemático sin cambio propuesto.

### RV-13 — Compactar el nodo conmutado del booster

- **Estado: CORREGIDO EN PCB; prueba de refresco pendiente.** Se ha acortado
  Q4.2–R10.2 de 15,94 mm a 2,34 mm, ahora a 0,25 mm y sin vías. Ese tramo
  conduce la corriente del transistor: no es sólo una señal de medida.
- **Evidencia actual:** Q4.3–L1.1 mide 8,88 mm; el nodo `Net-(D4-A)` suma
  13,00 mm a 0,60 mm. C5.1–L1.2 mide 5,19 mm. El retorno de R10 llega al
  cobre GND local. Se revisó el conjunto tras la recolocación, no sólo R10.
- **Acción:** ninguna recolocación adicional solicitada. Fue una mejora
  preventiva; no demuestra la causa de los fallos del prototipo anterior.
- **Cierre:** conexiones y DRC comprobados; validar refresco en prototipo.
  Criterio general:
  [TI SNVA731, §6](https://www.ti.com/lit/an/snva731/snva731.pdf), aplicado al
  circuito específico del panel, no como sustituto de su esquema.
- [ ] PCB corregida y revisada por el autor; esquemático sin cambio propuesto.

### RV-14 — D6 está junto al CP2104, no a la entrada USB

- **Revisión sobre guardado 19:29 (2026-09-13):** D6 mantiene su vía GND a
  1,11 mm y cobre local conectado. No se identifica otra corrección concreta
  necesaria en esta inspección; mantener posición por la faja. El ensayo ESD
  permanece pendiente, no equivale a un trabajo de enrutado pendiente.
- **Estado: POSICIÓN ACEPTADA; ensayo ESD pendiente.** Hipótesis: la descarga puede
  recorrer y acoplarse a más circuito antes de alcanzar el protector.
- **Evidencia:** los pads de datos de J3 están en x=55,66 mm y los de D6 en
  x=66,35 mm: unos 10,7 mm de separación horizontal. U3 queda inmediatamente
  después. D6 sí está conectado y dispone de una vía GND a unos 1,1 mm.
- **Decisión del autor:** la faja de pantalla impide acercar D6. Se retira la
  propuesta de recolocación; conservar la posición y revisar únicamente los
  ramales y el retorno GND. Restricción mecánica aceptada, no validación ESD.
- **Cierre:** revisar entrada/retorno de descarga y DRC; la inmunidad sólo se
  valida mediante ensayo ESD. [Criterio de colocación del fabricante Toshiba](https://toshiba.semicon-storage.com/eu/semiconductor/knowledge/e-learning/basics-of-tvs-diodes/chap5/chap5-1.html).
- [ ] PCB corregida y revisada por el autor; esquemático sin cambio propuesto.

### RV-15 — Cuatro taladros de posicionamiento excluidos del DRC

- **Corrección autorizada (2026-09-13):** los dos agujeros de posicionamiento
  de J3 pasan a NPTH en PCB y biblioteca local, conservando diámetro de
  0,70 mm y posiciones. Anclajes soldados y SW1 intactos. Desaparecen las
  cuatro infracciones de J3 por anular/padstack; sin errores nuevos.
- **Estado: J3 CORREGIDO; SW1 CONSERVADO POR DECISIÓN DEL AUTOR.** La huella
  importada trataba los agujeros mecánicos como PTH sin anular. El plano de
  J3 representa los posicionadores separados de los anclajes soldados.
- **Aclaración del autor:** los avisos de SW1 se excluyeron por cómo venía la
  huella. No modificar SW1 ni sus exclusiones en esta fase.
- **Cierre parcial:** los dos agujeros de J3 salen en el archivo NPTH y sus
  cuatro anclajes permanecen PTH. Aprobación física del autor pendiente.
- [ ] PCB corregida y revisada por el autor; esquemático sin cambio propuesto.

**Sin otro problema concreto detectado en esta pasada:** conexiones actuales
de GPIO/reset/latch, polaridad y pinout del motor, alimentación principal y
desacoplo local C26/C27. In1 y B.Cu mantienen planos de masa conectados; esto
no garantiza por sí solo todos los retornos. No se certifican impedancias USB,
EMC, temperaturas ni encaje de batería/flex/carcasa mediante DRC o estas vistas.

## Compatibilidad JLCPCB — configuración de 1 mm (2026-09-13)

Apilado y reglas actuales en README. Los informes DRC rellenan zonas en
memoria sin guardar cobre: al preparar el pedido, rellenar zonas y generar
archivos nuevos. Las exportaciones temporales no son el paquete definitivo.

### RV-16 — Tres vías GND demasiado próximas a la ranura

- **Estado: CORREGIDO por el autor; verificado con DRC** sobre el guardado
  19:29 del 2026-09-13. Las tres infracciones de borde ya no aparecen con
  límite 0,20 mm. La evidencia siguiente describe el estado anterior.
- **Evidencia:** JLC exige cobre–borde fresado ≥0,20 mm. Las vías de diámetro
  0,50 mm en (89,12;148,77), (91,65;148,77) y (95,77;148,77) mm dejan
  0,1904–0,1923 mm según DRC. Antes se comprobaban sólo 0,10 mm.
- **Acción aplicada:** el autor separó ligeramente las vías de la ranura.
- **Cierre:** rellenar zonas y repetir DRC con la regla de 0,20 mm.
- [ ] PCB corregida y revisada por el autor; esquemático sin cambio propuesto.

### RV-17 — «Plugged» no resuelve las vías dentro del pad del ESP32

- **Estado: GEOMETRÍA Y PASTA ACEPTADAS; soldadura pendiente de validar.**
  Se conservan las nueve ventanas de pasta. El autor ha dejado 12 vías
  exteriores de 0,30/0,50 mm y cuatro interiores de 0,20/0,45 mm, sin solapar
  los agujeros con la pasta. Margen interior de 0,020–0,034 mm aceptado.
- **Limitación:** JLC excluye del relleno con tinta las vías dentro de pads
  o próximas a sus aperturas. «Plugged» no garantiza su sellado.
- **Decisión:** no modificar pasta ni añadir relleno epoxi/cobre de oficio.
  La existencia de estas vías no demuestra por sí sola un fallo de soldadura.
- **Cierre:** comprobar calidad de montaje del prototipo.
  [Requisitos de vías JLCPCB](https://jlcpcb.com/help/article/pcb-via-covering).
- [ ] PCB/proceso revisados por el autor; esquemático sin cambio propuesto.

**Resto del contraste:** tamaños de vía y resultado DRC actuales en el resumen
de cierre anterior. Los avisos de texto de C2 y el solapamiento Q4–D4 ya no
aparecen tras los ajustes del autor.

La ranura fresada estrecha y el tratamiento HASL/máscara deben confirmarse en
CAM con sus tolerancias; los Gerber anteriores no sirven para esta versión.
La expansión global de máscara de 0,051 mm se conserva para no alterar las
aperturas en esta fase; JLC publica actualmente 1:1 y puede compensar en CAM.
El DRC con 0,09 mm entre apertura y cobre ajeno no añade errores.
No se ha pedido control de impedancia de precisión ni cambiado el laminado
económico TG135 a otro de más prestaciones. Fuente de límites:
[capacidades de JLCPCB](https://jlcpcb.com/capabilities/pcb-capabilities).

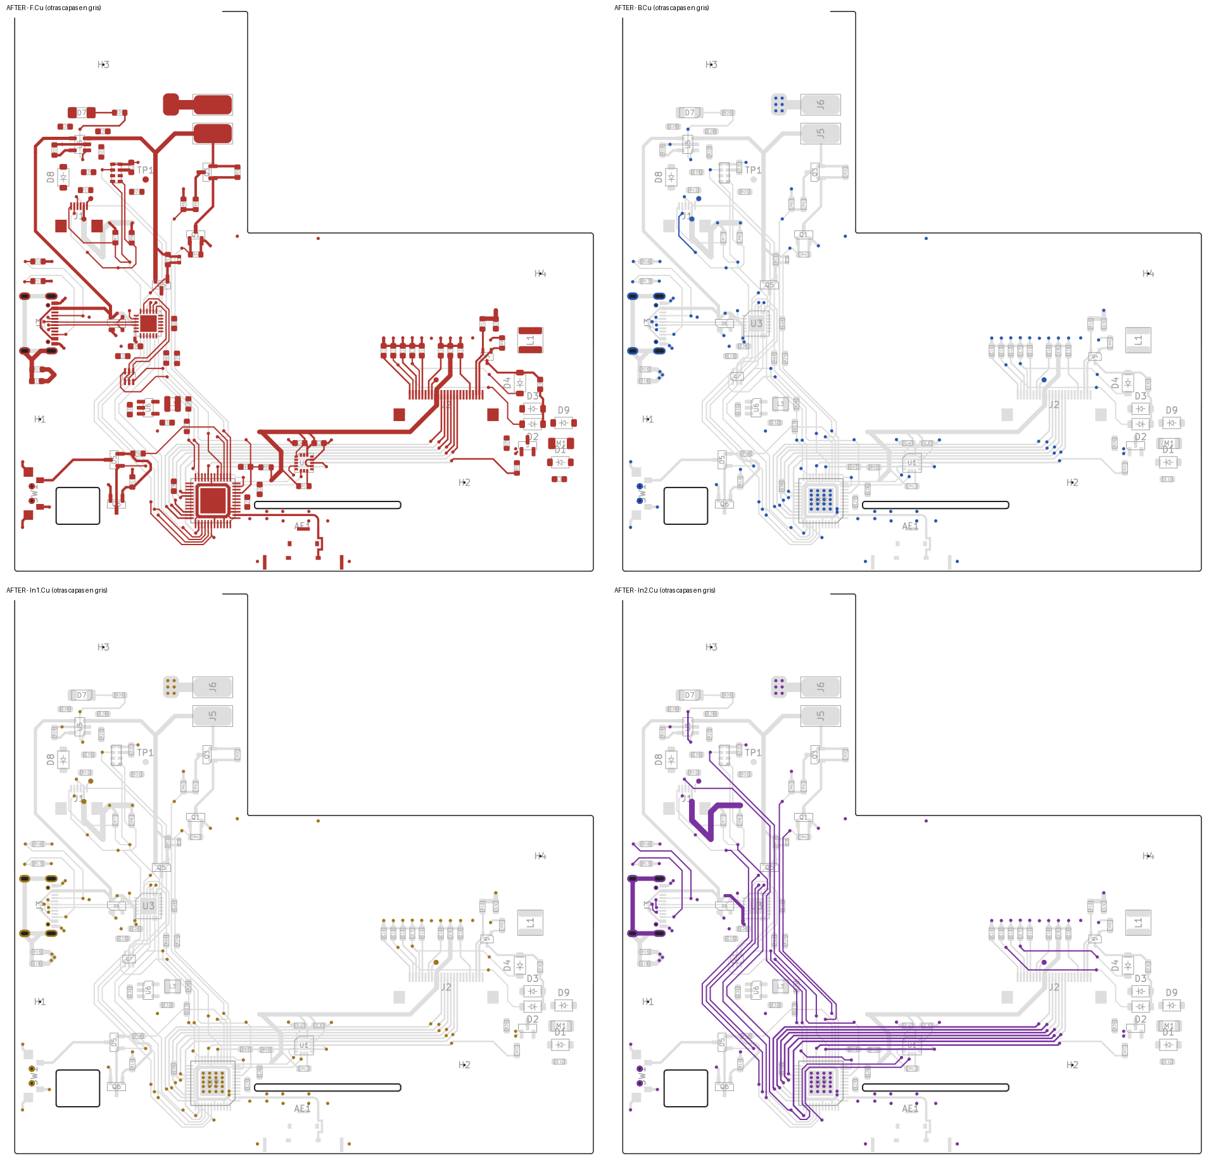
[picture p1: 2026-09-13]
documentation/pcb_preparacion/despues.png

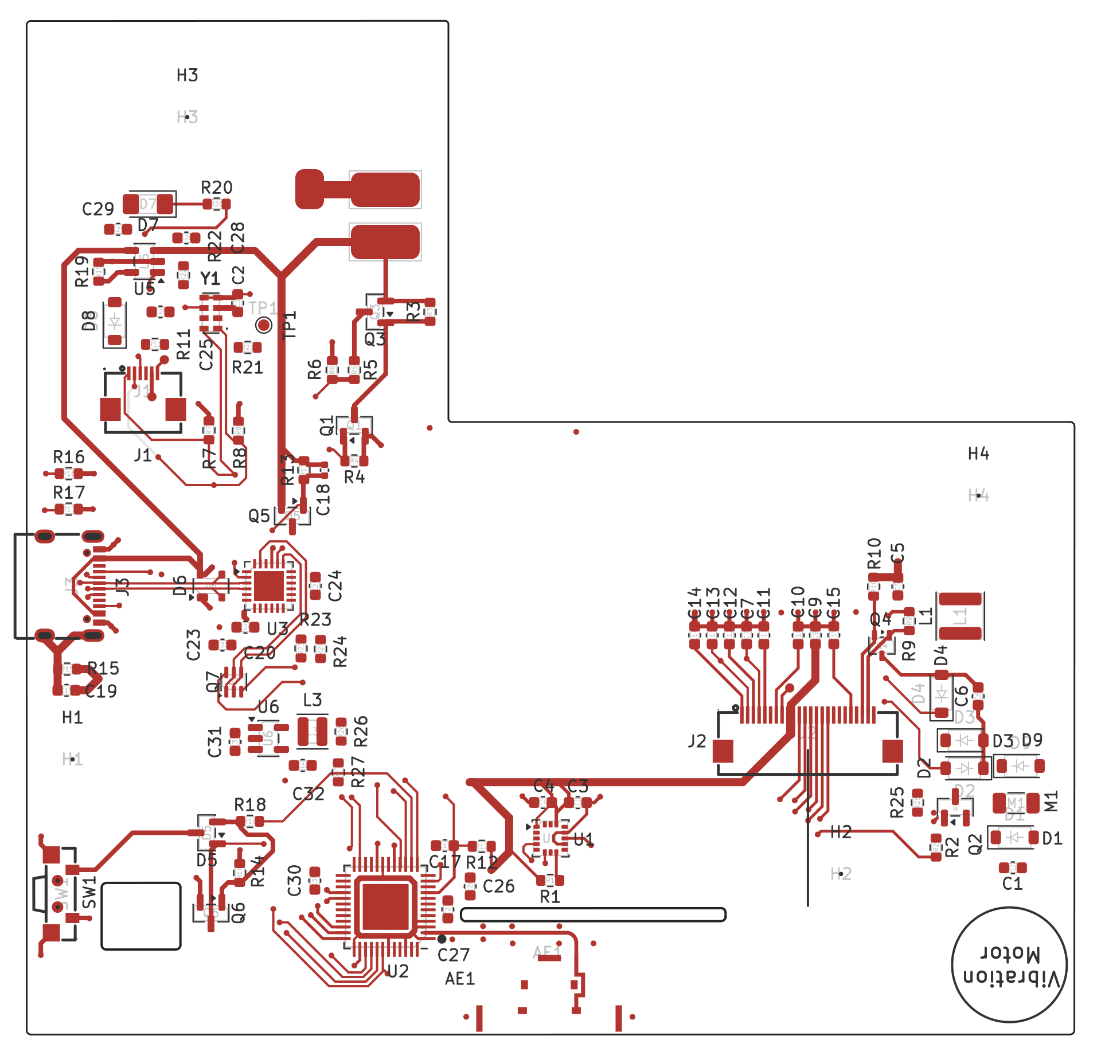
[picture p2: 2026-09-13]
documentation/pcb_preparacion/colocacion.png

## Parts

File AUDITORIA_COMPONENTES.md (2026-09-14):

# Auditoría eléctrica por componentes

**Autor:** Cosmin Dobrescu
**Última revisión:** 2026-09-13
**Alcance:** esquema actual, netlist exportado con KiCad 10 y datasheets del
fabricante. Se revisan también dependencias entre bloques; la PCB queda fuera
de esta auditoría.

Estados: `CORRECTO`, `CONDICIONAL`, `CORREGIR`, `DECISIÓN ACEPTADA` y
`NO VERIFICABLE`.

## Resultado ejecutivo

### Sin correcciones eléctricas obligatorias abiertas

`R26` y `R27` se han revisado de nuevo y se conservan; el detalle y el margen
aceptado constan en la tabla del regulador.

### Corregido en esta revisión

1. **Booster de pantalla (`R9`)**. R9 queda en 1 MΩ entre `GDR` y
   GND, en paralelo con la puerta de Q4, como R1 en la figura 12 del datasheet
   específico del GDEY042T81-T02. Reutiliza el valor de R15 y no añade otro
   valor al BOM.

### Decisiones aceptadas

- **RTC (`Y1`)**: se conserva la alimentación permanente desde `VBAT_RAW` y el
  bus I²C a `+3V3`; no se trata como fallo pendiente.
- **Cargador (`U5`)**: se acepta el TP4054 montado y se cierra la revisión de su
  tensión final.
- **RF (`U2`, `AE1`)**: se conserva la conexión directa mediante pista de 50 Ω.
  No se reserva una red π porque no se dispone de medida RF para determinar sus
  valores. El riesgo se acepta y se deja para una futura revisión con VNA.
- **Salida `+3V3` (`R26`, `R27`)**: se conservan 453 kΩ/100 kΩ. Producen
  3,318 V nominales y se aceptan como alimentación práctica de 3,3 V para el
  FT6336U; no se abre una corrección del divisor.

### Debe decidirse o medirse

1. **Motor (`M1`, `Q2`)**. Compra por AliExpress; falta confirmar modelo exacto
   y corriente de arranque del motor adquirido. Si el arranque real es
   unos 90 mA, Q2, D1 y D9 son razonables. Si es realmente 901 mA, supera los
   500 mA absolutos del S8050 y el conjunto no es válido.
2. **Bus I²C a 400 kHz (`R7`, `R8`)**. 5,1 kΩ da un máximo teórico aproximado
   de 69 pF para cumplir 300 ns de subida. Hay cuatro dispositivos, PCB y flex;
   no puede afirmarse 400 kHz sin estimar o medir la capacitancia. Todos los
   dispositivos admiten 100 kHz; FT6336U declara 400 kHz pero conserva varios
   tiempos mínimos propios de modo estándar. Usar 100 kHz hasta medir.
3. **Reset táctil (`R11`, `R28`, `C25`, `D8`)**. Mejora preventiva aplicada:
   R11 y R28 de 1 kΩ en paralelo dan 500 Ω efectivos. Con el pull-up interno
   de 3 kΩ, el nivel bajo calculado a 3,3 V pasa de 0,825 V a ≈0,47 V,
   frente al límite de 0,99 V. Ambas usan `C21190`; omitir R28 recupera 1 kΩ.
   C25 conserva una constante de carga nominal de unos 30 ms y D8 acelera
   la descarga al apagar. Comprobar el reset en prototipo: cálculo nominal,
   no medida ni tolerancia garantizada del pull-up. La figura 3-10 del FT6336U dibuja
   Trsi desde el inicio del pulso de reset: se conserva la secuencia de
   60 ms en bajo y ≥300 ms de espera tras liberar GPIO4. No se ha encontrado
   un fallo temporal que obligue a alargarla.
4. **RF y mecánica**. La revisión digital de PCB e impedancia de pista ya está
   realizada; quedan alcance RF y encaje físico por validar. La decisión de
   omitir la red π ya está cerrada.

## Revisión por referencias

### Procesador, alimentación de 3,3 V y RF

| Referencias | Estado | Justificación |
| --- | --- | --- |
| U2 | CORRECTO | ESP32-PICO-D4, 3,0–3,6 V. GPIO34/35 se usan sólo como entradas. GPIO9 y GPIO10 pueden usarse libremente en el PICO-D4; la flash interna usa otro mapeo del SiP. Los pines de alimentación y masa coinciden con el datasheet. |
| C26, C27 | CORRECTO | 10 µF + 100 nF sobre `+3V3`, combinación indicada por el circuito periférico de Espressif. Deben quedar junto al grupo de alimentación del PICO. |
| C30 | CORRECTO | 100 nF exclusivamente entre `VDD_SDIO` y GND, como indica Espressif. No debe unirse `VDD_SDIO` a `+3V3`. |
| R12, C17 | CORRECTO | 10 kΩ + 1 µF en EN produce unos 10 ms y mantiene el pin definido. Es compatible con el auto-reset; el latch puede exigir mantener pulsado durante programación. |
| U6 | CORRECTO | TLV62568DBVR: VIN 2,5–5,5 V, salida de 1 A, EN definido y unido a VIN. `VSYS` de 0–4,2 V entra en rango. |
| R26, R27 | DECISIÓN ACEPTADA | Son el divisor de realimentación del TLV: 453 kΩ/100 kΩ produce 3,318 V nominal. Apilando `VFB` del TLV (0,588–0,612 V), R26 de 0,1 % y R27 de 1 %, resulta aproximadamente 3,22–3,42 V. El datasheet del FT6336U es internamente conservador/inconsistente: anuncia funcionamiento a 2,8–3,6 V, mientras su tabla DC caracteriza VDDA/VDD3 hasta 3,3 V y fija 3,6 V como máximo absoluto. Se conserva el divisor: el extremo calculado no plantea sobretensión destructiva y el valor nominal corresponde a un rail de 3,3 V. |
| L3 | CORRECTO | 1 µH; 3,6 A térmicos mínimos, 5 A de saturación mínimos y DCR máxima de 42 mΩ. Supera ampliamente el límite de corriente del TLV. TI valida 1 µH con 10 µF para salidas de al menos 1,8 V. |
| C31, C32 | CORRECTO | 10 µF X5R/X7R de baja ESR. La entrada supera los 4,7 µF recomendados y la salida está dentro de 10–47 µF. El derating por polarización debe considerarse en PCB/BOM. |
| U6, L3, C31, C32, R26, R27 | CONDICIONAL PCB | C31 debe quedar junto a VIN/GND; SW-L3-C32 debe formar un bucle corto y ancho; FB debe alejarse de SW. Puede añadirse 6,8 pF en paralelo con R26 para mejorar transitorios, pero TI lo presenta como opcional, no como requisito de estabilidad. |
| AE1 | DECISIÓN ACEPTADA | Antena JAE AN012400C00 de 2,4–2,5 GHz y 50 Ω. Se conecta directamente a U2 mediante una pista corta y controlada de 50 Ω. Se omite deliberadamente la red π porque sus valores exigirían medida RF; una revisión futura podrá incorporarla y ajustarla con VNA. |

**Dependencia de batería baja:** el TLV entra en ciclo del 100 % cuando
`VBAT_RAW` se aproxima a 3,3 V. Aproximadamente, `VOUT = VIN - I·(RDS(on)+DCR)`;
la protección de la celda puede cortar demasiado tarde para el ESP32. El
firmware debe apagar mediante el latch antes de brownouts repetidos.

### Pantalla GDEY042T81-T02 y booster SSD1683

| Referencias | Estado | Justificación |
| --- | --- | --- |
| J2 | CORRECTO | La numeración está invertida respecto al FPC físico de forma intencionada. El netlist reproduce los 24 pines del panel: VCOM→J2.1 hasta NC→J2.24. VDDIO y VCI van a `+3V3`; BS1 va a GND para SPI de 4 hilos; los NC permanecen abiertos. |
| C5, C6 | CORRECTO | 4,7 µF/25 V en entrada y bomba, exactamente los valores C4 y C3 del circuito específico del panel. |
| C7, C9–C15 | CORRECTO | 1 µF/50 V; cubren PREVGH, VDD, VSH1/VSH2, VSL, VGL y VCOM con margen sobre los 25 V prescritos. |
| L1 | CORRECTO | FHD4020S-470MT, 47 µH, 660 mA nominal y 1,3 A de saturación. Coincide con los 47 µH/500 mA del panel. |
| D2–D4 | CORRECTO | C236079 es onsemi MBR0530T3G: 30 V, 500 mA, 5,5 A de pulso y `VF <= 0,43 V` a 500 mA. Cumple tanto el panel como la tabla genérica del SSD1683. Orientaciones verificadas contra el circuito de referencia. |
| Q4 | CORRECTO | SI1308EDL C7603347, exactamente el modelo pedido por Good Display: 30 V, 1,4 A y pinout G1/S2/D3. |
| R10 | CORRECTO | 2,2 Ω entre RESE y GND, valor exacto del panel. |
| R9 | CORREGIDO | 1 MΩ entre `GDR` y GND, en paralelo con la puerta de Q4. Corresponde a R1 de la figura 12 del datasheet específico del panel. Usa C22935, igual que R15. |
| GPIO5/9/10/18/19/23 | CORRECTO | CS, RES, DC, SCK, BUSY y MOSI son compatibles. GPIO5 es pin de strapping, pero el panel sólo presenta una entrada; debe comprobarse que no fuerza nivel durante reset. GPIO9/10 son libres en ESP32-PICO-D4. |

### Táctil e I²C

| Referencias | Estado | Justificación |
| --- | --- | --- |
| J1 | CORRECTO EN ESQUEMA | J1.1=SCL, J1.2=SDA, J1.3=INT, J1.4=RSTN, J1.5=`+3V3`, J1.6=GND. Mecánica y correspondencia del flex siguen pendientes de PCB. |
| R7, R8 | CONDICIONAL | 5,1 kΩ limita la corriente LOW a unos 0,65 mA, válida para todos los dispositivos. 400 kHz depende de la capacitancia total; 100 kHz es el ajuste conservador. |
| R11, R28, C25, D8 | CORRECTO / PRUEBA PENDIENTE | R11 y R28 de 1 kΩ en paralelo mejoran el nivel bajo del reset; conexiones verificadas en esquema y PCB. Mantener GPIO4 open-drain LOW ≥60 ms, liberar y esperar ≥300 ms. No conducir nivel alto desde el GPIO. |
| INT_TOUCH/GPIO35 | CORRECTO | GPIO35 es de entrada y la salida INT del FT6336U es CMOS; no se exige pull-up externo. |
| Direcciones I²C | CORRECTO | LIS3DH=0x19 por SDO interno alto, RV-8803=0x32 y FT6336U=0x38; no hay colisión. |

### Acelerómetro

| Referencias | Estado | Justificación |
| --- | --- | --- |
| U1 | CORRECTO | LIS3DH alimentado a 3,3 V. VDD y VDD_IO aparecen simultáneamente. CS está alto para I²C; SDO puede quedar abierto porque incorpora pull-up y selecciona 0x19. ADC1–ADC3 pueden quedar abiertos. |
| C3, C4 | CORRECTO | 100 nF + 10 µF sobre el mismo `+3V3`, combinación prescrita por ST junto al pin 14. C3 y C4 no son redundantes: cubren alta frecuencia y reserva local. |
| R1 | CORRECTO | 10 kΩ mantiene CS alto y fija modo I²C. |
| ACC_INT1, ACC_INT2 | CORRECTO | GPIO14 admite E/S y GPIO34 es sólo entrada; ambas señales son salidas programables del LIS3DH. |

### RTC

| Referencias | Estado | Justificación |
| --- | --- | --- |
| Y1 | DECISIÓN ACEPTADA | Se mantiene alimentado permanentemente desde `VBAT_RAW` y conectado al I²C de `+3V3`. La revisión queda cerrada por decisión de diseño. |
| C2 | CORRECTO | 100 nF local; Micro Crystal recomienda 10–100 nF. |
| R22 | CORRECTO | 10 kΩ a `+3V3` para `INT`, salida open-drain. Evita aplicar `VBAT_RAW` al ESP32. |
| R21, TP1 | CORRECTO | EVI es una entrada y no debe flotar. R21 la eleva a `VBAT_RAW`; TP1 permite un futuro evento activo bajo. |
| CLKOE/CLKOUT | CORRECTO | CLKOE a GND y CLKOUT sin conectar deshabilitan una salida no utilizada. |

### USB, CP2104 y programación

| Referencias | Estado | Justificación |
| --- | --- | --- |
| J3 | CORRECTO | USB-C 2.0: pares A6/B6 y A7/B7 unidos; SBU abiertos; VBUS y GND correctos. |
| R16, R17 | CORRECTO | 5,1 kΩ a GND en CC1/CC2: anuncio Rd de dispositivo consumidor. |
| D6 | CORRECTO | SP0503BAHTG es el protector que recomienda Silicon Labs; D+, D− y VBUS protegidos, común a GND. Debe quedar junto al conector. |
| R15, C19 | CORRECTO | 1 MΩ en paralelo con 4,7 nF entre shield y GND: descarga electrostática y acoplo de alta frecuencia sin unión DC rígida. Su efectividad depende del trazado. |
| U3 | CORRECTO ELÉCTRICAMENTE | Conexión self-powered con regulador bypass: VIO/VDD/REGIN a `+3V3`, exactamente como figura 9 del CP2104. |
| C20, C23 | CORRECTO | 100 nF + 1 µF locales en la alimentación del CP2104. |
| R23, R24 | CORRECTO | Divisor 24 kΩ/47 kΩ desde VBUS, exactamente el recomendado cuando VBUS puede existir con VDD apagado. Da unos 3,31 V con VBUS=5 V. |
| C24 | CORRECTO | 4,7 µF en VPP. Este pin no se utiliza en el funcionamiento previsto y el condensador no afecta al USB normal. |
| Q7 | CORRECTO | UMH3N con pinout E1/B1/C2/E2/B2/C1; la conexión cruzada DTR/RTS evita que ambas señales mantengan simultáneamente EN y GPIO0 en reset. |

### Cargador y batería

| Referencias | Estado | Justificación |
| --- | --- | --- |
| U5 | CORRECTO / DECISIÓN ACEPTADA | TP4054 C5381776, pinout y aplicación coincidentes. Entrada USB de 5 V en rango, regulación térmica y terminación C/10. Se acepta el componente montado y se cierra esta revisión. |
| R19 | CORRECTO | 5,1 kΩ produce unos 196 mA por `IBAT=1000/RPROG`. Con la dispersión indicada por el fabricante puede apartarse sensiblemente del nominal, pero sigue siendo moderado para 600–700 mAh. |
| C29, C28 | CORRECTO | 1 µF en VDD y 10 µF en BAT coinciden con la aplicación del fabricante. Deben quedar junto a U5. |
| D7, R20 | CORRECTO | LED desde VBUS hacia STAT open-drain mediante 1 kΩ. Corriente compatible con STAT y visible sin una carga relevante. |
| Sin power-path | DECISIÓN ACEPTADA | Con el equipo encendido, U5 no distingue corriente de batería y corriente del sistema: la carga puede ralentizarse, no terminar o ciclar. No crea una conexión prohibida, pero es una consecuencia funcional deliberada. |
| Batería | NO VERIFICABLE | Se conoce formato y capacidad aproximada, pero no modelo, corriente máxima, umbrales de protección ni tensión de carga admitida. |

### Latch, botón y medida de batería

| Referencias | Estado | Justificación |
| --- | --- | --- |
| Q5 | CORRECTO | CJ3415 P-MOS como interruptor high-side, source a `VBAT_RAW` y drain a `VSYS`. Tensiones y corriente tienen margen. |
| Q6 | CORRECTO | CJ2312 N-MOS tira de la puerta de Q5; admite mando de 3,3 V. |
| D5 | CORRECTO | BAT54C de cátodo común: el pulsador descarga las puertas de Q5/Q6 por las dos ramas sin unirlas directamente. |
| R13, C18 | CORRECTO CON LIMITACIÓN | 300 kΩ y 100 nF producen 30 ms nominales. Retrasan la liberación de Q5, pero no son un supervisor ni garantizan inmunidad frente a toda alimentación parcial. |
| R14, R18 | CORRECTO | 100 kΩ mantiene Q6 apagado y 1 kΩ limita el mando desde GPIO25. El firmware debe elevar GPIO25 antes de soltar el pulsador. |
| SW1 | CORRECTO | Contacto de encendido a GND y shield a GND; pinout compatible con TSC02-TDW1FH3.5. |
| Q1, Q3 | CORRECTO | CJ2312 + CJ3415 conmutan el divisor desde el lado alto; apagado deja ADC_BATT a GND por R6 y evita consumo permanente. |
| R3, R4 | CORRECTO | Pull-ups de 100 kΩ mantienen apagados Q3 y Q1 respectivamente. |
| R5, R6 | CORRECTO | 10 kΩ/10 kΩ divide 4,2 V a 2,1 V, dentro del pin del ESP32. Firmware debe usar atenuación ADC suficiente y calibración; GPIO33 pertenece a ADC1 y puede medirse con Wi-Fi activo. |

### Motor

| Referencias | Estado | Justificación |
| --- | --- | --- |
| M1 | NO VERIFICABLE | Sin modelo ni especificación cerrada; la huella actual tampoco demuestra compatibilidad mecánica. |
| Q2 | CONDICIONAL | S8050 C20069125, pinout B1/E2/C3, 500 mA absolutos. R2=1 kΩ entrega unos 2,6 mA de base; es razonable para 70–90 mA, pero no garantiza 901 mA. |
| R2, R25 | CORRECTO PARA 90 mA | 1 kΩ limita base y 100 kΩ mantiene Q2 apagado durante reset. Si el motor real exige mucha más corriente debe rediseñarse el driver, no sólo cambiar R2. |
| D1 | CORRECTO PARA 90 mA | MBR0530 como rueda libre, 30 V/500 mA y orientación correcta. |
| D9 | CORRECTO PARA 90 mA | MBR0530 en serie desde `VSYS` a `VMOTOR`. A 70–100 mA su caída mantiene un motor de rango 2,5–4 V por debajo o cerca de 4 V con batería llena. No protege un motor de 901 mA. |
| C1 | CORRECTO | 100 nF en paralelo con M1 reduce ruido de escobillas. PWM es opcional; D1 mantiene continuidad de corriente. |

### Pasivos y encapsulados restantes

| Referencias | Estado | Justificación |
| --- | --- | --- |
| C1–C4, C17, C20, C23, C25–C32 | CORRECTO | Tensiones nominales de los MLCC superan 4,2/5 V. Los valores y dieléctricos corresponden a sus funciones; la validez final depende de colocación y derating DC. |
| C5–C7, C9–C15, C24 | CORRECTO | 25 o 50 V según redes auxiliares de pantalla/VPP; no deben sustituirse por MLCC de menor tensión sin revisar derating. |
| R1–R28 salvo R26 y R27 | CORRECTO | Valores, potencia 0603 y tolerancias son suficientes para las corrientes calculadas. R26/R27 se evalúan aparte con la salida del TLV; R11/R28 en el bloque de reset. |
| J5, J6, TP1 | CONDICIONAL PCB | Son conexiones/puntos de prueba; eléctricamente correctos, pero su existencia y acceso dependen de la PCB final. |

## Dependencias cruzadas verificadas

- `+3V3` nominal es compatible con ESP32, CP2104, LIS3DH, panel y táctil. El
  margen superior del FT6336U queda aceptado pese a la discrepancia interna de
  su datasheet entre 3,3 V caracterizados y 3,6 V anunciados.
- El motor ya no carga `+3V3`; toma energía de `VSYS` a través de D9.
- El booster de pantalla coincide con el circuito específico de Good Display,
  incluida R9 ya corregida a 1 MΩ.
- GPIO9/10 no interfieren con la flash interna del ESP32-PICO-D4.
- Las direcciones I²C no colisionan. La interfaz del RTC se conserva como está
  por decisión de diseño.
- CP2104 apagado con VBUS presente queda en la topología self-powered prevista
  por Silicon Labs y ya no debe realimentar directamente `+3V3`.
- La carga simultánea sin power-path es eléctricamente posible, pero modifica
  terminación y tiempo de carga.

## Fuentes principales

- [ESP32-PICO series](documentation/datasheets/ESP32-PICO-series.pdf) y
  [guía de hardware](documentation/esp32_hardware_design_guidelines_en.pdf).
- [GDEY042T81-T02](documentation/datasheets/GDEY042T81-T02.pdf) y
  [SSD1683](documentation/datasheets/SSD1683.pdf).
- [FT6336U](documentation/datasheets/FT6336U.pdf),
  [LIS3DH](documentation/lis3dh_datasheet.pdf) y
  [RV-8803-C7 application manual](RV-8803/RV-8803-C7_App-Manual.pdf).
- [CP2104](documentation/cp2104-1397921.pdf),
  [TP4054 exacto](documentation/datasheets/TP4054-JSMSEMI-C5381776.pdf),
  [S8050 exacto](documentation/datasheets/S8050-R+O-C20069125.pdf) y
  [SI1308EDL exacto](documentation/datasheets/SI1308EDL-TECH-PUBLIC-C7603347.pdf).
- [TLV62568, TI](https://www.ti.com/lit/ds/symlink/tlv62568.pdf) y
  [MBR0530T3G, onsemi](https://www.onsemi.com/download/data-sheet/pdf/mbr0530t1-d.pdf).

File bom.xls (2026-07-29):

Comment | Designator | Footprint | JLCPCB Part # | Qty | Ext.Price($)
USB_C_Receptacle_USB2.0_16P | J3 | USB-C-SMD_TYPE-C-16PIN-2MD-073 | C2765186 | 3 | 0.20
RV-8803-C7-TA-QC | Y1 | MICROCRYSTAL_RV-8803-C7-TA-QC | C2846926 | 2 | 0.00
MBR0530 | D1,D2,D3,D4 | D_SOD-123 | C77336 | 12 | 0.40
Touch | J1 | FPC-SMD_P0.50-6P_QCHF-SM-H2.0 | C262287 | 4 | 0.57
SI1308EDL | Q4 | SOT-323_SC-70 | C7603347 | 6 | 0.54
1uH | L2 | 0805 | C1042 | 20 | 0.82
TP4054 | U5 | SOT-23-5 | C5381776 | 10 | 0.15
CJ3415 | Q3,Q5 | SOT-23 | C2910186 | 8 | 0.42
0.1uF | C17,C3 | 0603 | C14663 | 20 | 0.06
0.47R | R10 | 0603 | C23411 | 20 | 0.09
LIS3DH | U1 | LGA-16_3x3mm_P0.5mm_LayoutBorder3x5y | C15134 | 2 | 2.03
TSC02-TDW1FH3.5 | SW1 | SW-SMD_L7.8-W3.5-P4.20-EH | C22362983 | 5 | 0.12
SP0503BAHTG | D6 | SOT-143 | C3040626 | 5 | 0.48
ESP32-PICO-D4 | U2 | QFN-48-1EP_7x7mm_P0.5mm_EP3.5x3.5mm | C193707 | 2 | 8.51
4.7uF/25V | C5,C6 | 0603 | C69335 | 20 | 0.34
CP2104 | U3 | QFN-24-1EP_4x4mm_P0.5mm_EP2.6x2.6mm | C47742 | 2 | 4.48
10uF | C2,C21,C22,C4 | 0603 | C19702 | 20 | 0.20
10uH/1A | L1 | L_Vishay_IFSC-1515AH_4x4x1.8mm | C602032 | 5 | 0.31
UMH3N | Q7 | SOT-363_SC-70-6 | C62892 | 6 | 0.29
CJ2312 | Q1,Q6 | SOT-23 | C23521 | 8 | 0.34
5.1k | R16,R17 | 0603 | C23186 | 20 | 0.03
BAT54C | D5 | SOT-23 | C22466350 | 10 | 0.14
100nF | C18 | 0402 | C1525 | 20 | 0.03
Screen | J2 | FPC-SMD_P0.50-24P_QCHF-SM-H2.0 | C262683 | 2 | 0.32
1M0 | R15 | 0603 | C22935 | 20 | 0.03
1uF | C10,C11,C12,C13,C14,C15,C16,C7,C8,C9,C1,C20 | 0603 | C15849 | 34 | 0.26
ADP2108AUJ-3.3 | U4 | TSOT-23-5 | C143875 | 2 | 0.00
10K | R1,R11,R12,R19,R5,R6,R7,R8,R9 | 0603 | C25804 | 28 | 0.04
1k | R18,R2,R20 | 0603 | C21190 | 20 | 0.03
S8050 | Q2 | SOT-23 | C20069125 | 10 | 0.10
100K | R14,R3,R4 | 0603 | C25803 | 20 | 0.04
300k | R13 | 0603 | C23024 | 20 | 0.03
4.7nF | C19 | 0603 | C53987 | 20 | 0.06
LED | D7 | 1206 | C84270 | 15 | 0.35

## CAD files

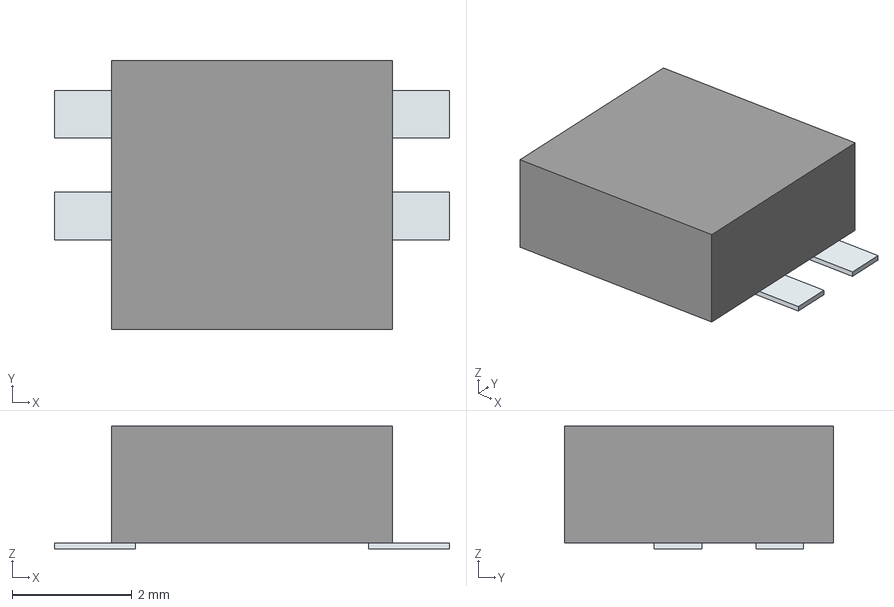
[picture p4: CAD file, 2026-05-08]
EVQ-PUA02K/EVQ-PUA02K.stp
6.60 x 4.50 x 2.05 mm
Pins

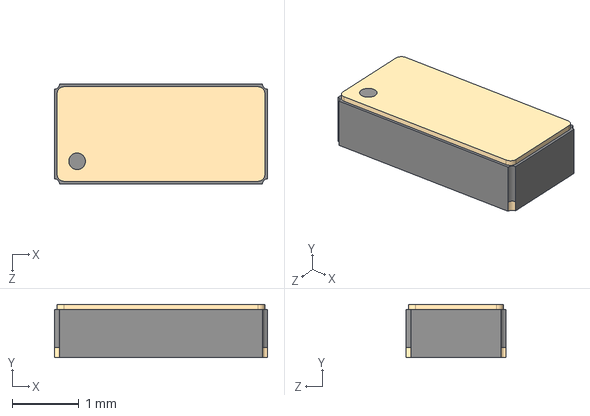
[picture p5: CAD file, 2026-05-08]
RV-8803/RV-8803-C7-TA-QC.step
3.20 x 0.8 x 1.50 mm

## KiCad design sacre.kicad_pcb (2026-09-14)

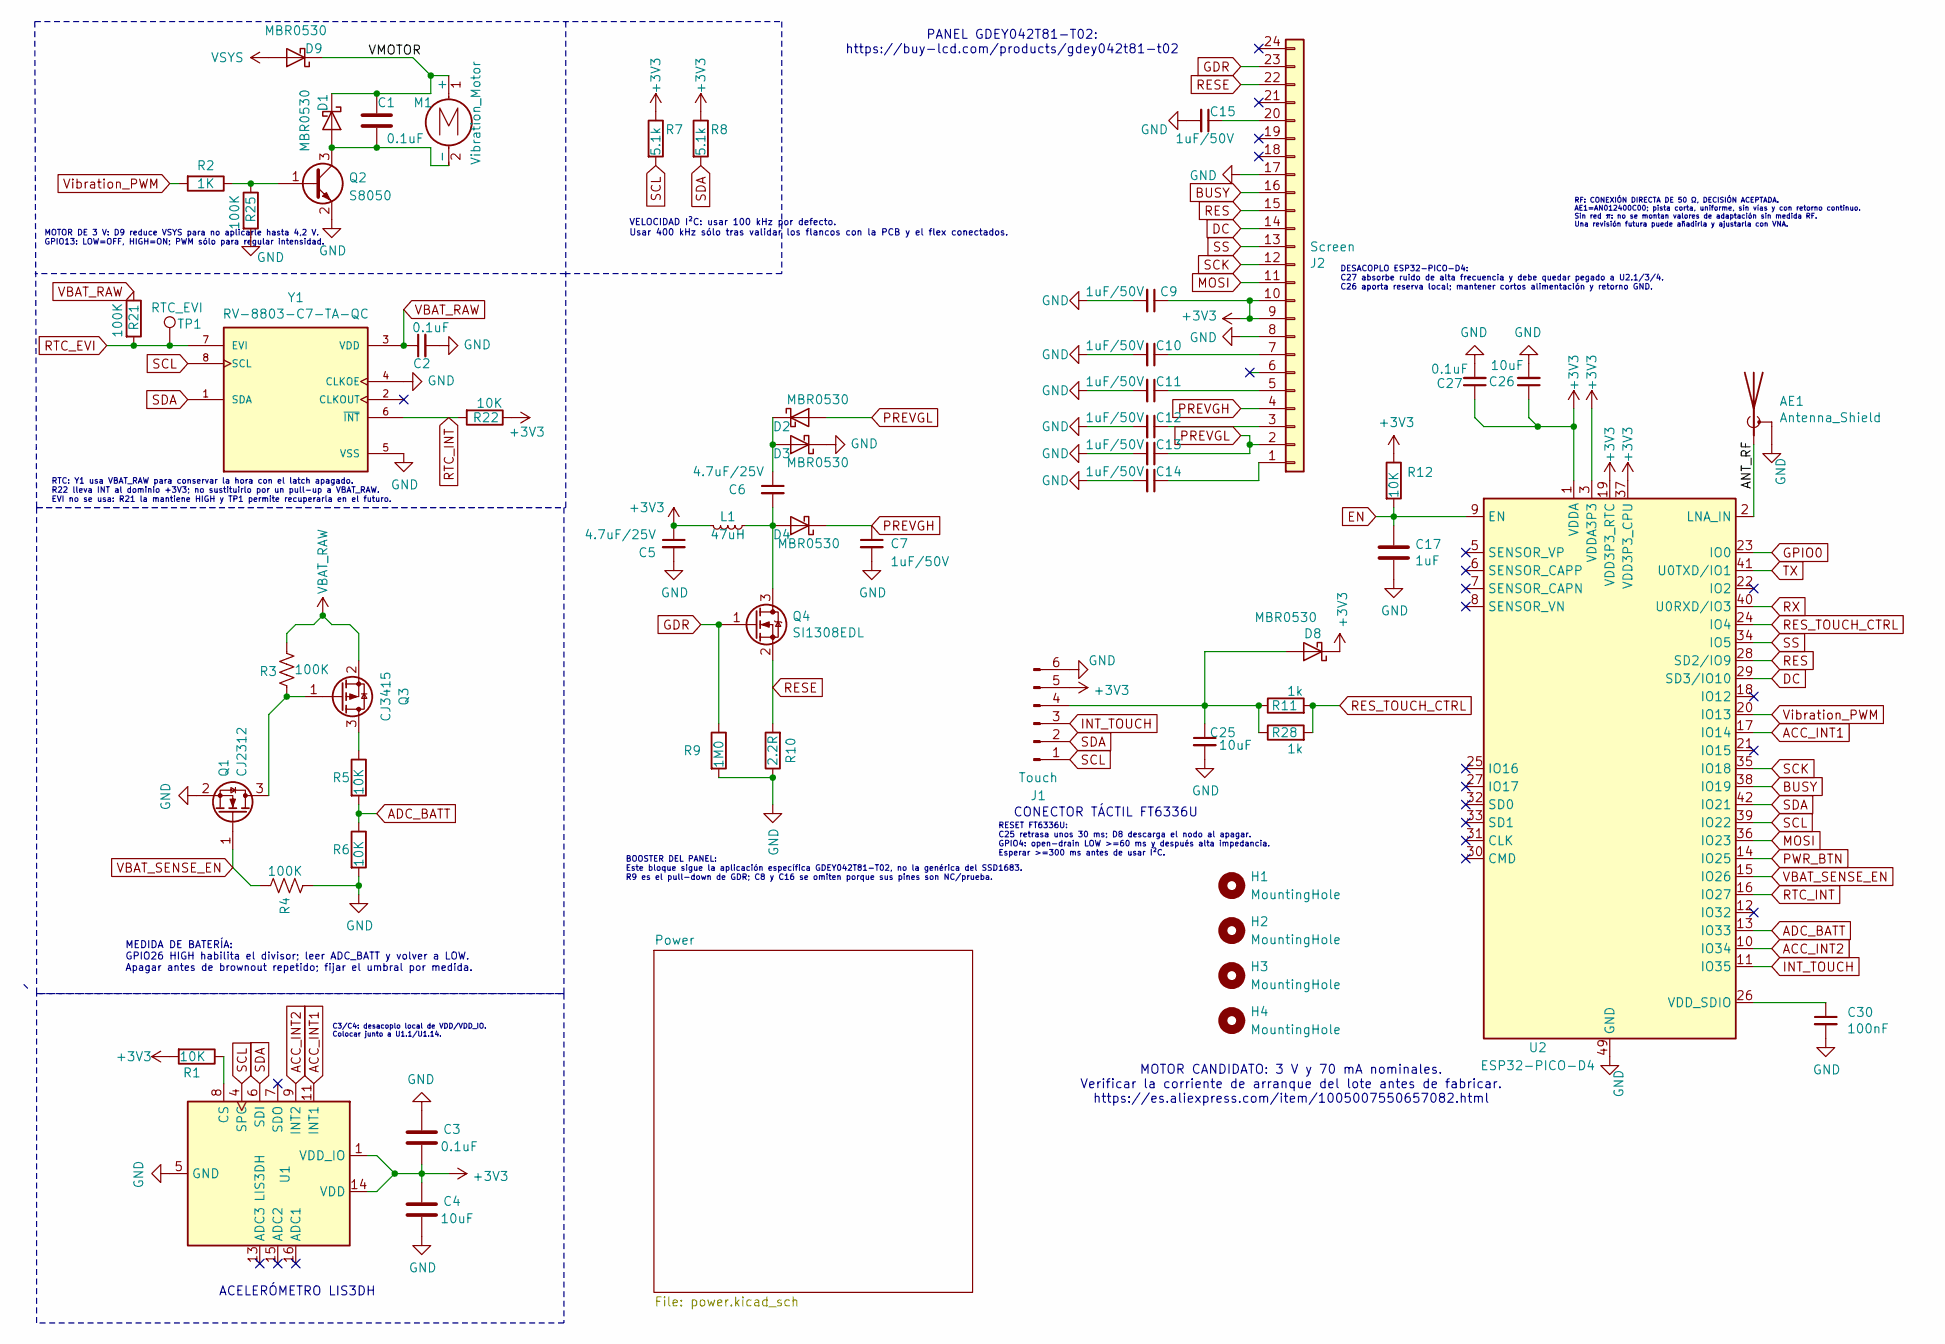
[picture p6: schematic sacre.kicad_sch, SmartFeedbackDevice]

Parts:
AE1: Antenna_Shield; AN012400C00R3200; LCSC Part # C5943777
C1, C2, C3, C27: 0.1uF; C_0603_1608Metric; LCSC Part # C14663
C4, C25, C26: 10uF; C_0603_1608Metric; LCSC Part # C19702
C5, C6: 4.7uF/25V; C_0603_1608Metric; LCSC Part # C69335
C7, C9, C10, C11, C12, C13, C14, C15: 1uF/50V; C_0603_1608Metric; LCSC Part # C15849
C17: 1uF; C_0603_1608Metric; LCSC Part # C15849
C30: 100nF; C_0603_1608Metric; LCSC Part # C14663
D1, D8, D9: MBR0530; D_SOD-123; LCSC Part # C77336
D2, D3, D4: MBR0530; D_SOD-123; LCSC Part # C236079
H1, H2, H3, H4: MountingHole; MountingHole_2.7mm_M2.5
J1: Touch; FPC-SMD_P0.50-6P_QCHF-SM-H2.0; LCSC Part # C262287
J2: Screen; FPC-SMD_P0.50-24P_QCHF-SM-H2.0; LCSC Part # C262683
L1: 47uH; L_Changjiang_FNR4020S; MPN FHD4020S-470MT; LCSC Part # C843300
M1: Vibration_Motor; C_1206_3216Metric
Q1: CJ2312; SOT-23; LCSC Part # C23521
Q2: S8050; SOT-23; LCSC Part # C20069125
Q3: CJ3415; SOT-23; LCSC Part # C2910186
Q4: SI1308EDL; SOT-323_SC-70; LCSC Part # C7603347
R1, R5, R6, R12, R22: 10K; R_0603_1608Metric; LCSC Part # C25804
R2: 1K; R_0603_1608Metric; LCSC Part # C21190
R3, R4, R21, R25: 100K; R_0603_1608Metric; LCSC Part # C25803
R7, R8: 5.1k; R_0603_1608Metric; LCSC Part # C23186
R9: 1M0; R_0603_1608Metric; LCSC Part # C22935
R10: 2.2R; R_0603_1608Metric; LCSC Part # C22939
R11, R28: 1k; R_0603_1608Metric; LCSC Part # C21190
TP1: RTC_EVI; TestPoint_Pad_D1.0mm
U1: LIS3DH; LGA-16_3x3mm_P0.5mm_LayoutBorder3x5y; LCSC Part # C15134
U2: ESP32-PICO-D4; QFN-48-1EP_7x7mm_P0.5mm_EP3.5x3.5mm; LCSC Part # C193707
Y1: RV-8803-C7-TA-QC; MICROCRYSTAL_RV-8803-C7-TA-QC; PARTREV 2.0; LCSC Part # C2846926

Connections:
+3V3: C3.2, C4.1, C5.1, C9.1, C26.1, C27.1, D8.1 (K), J1.5, J2.9, J2.10, L1.2, R1.2, R7.1, R8.1, R12.1, R22.1, U1.1 (VDD_IO), U1.14 (VDD), U2.1 (VDDA), U2.3 (VDDA3P3), U2.4 (VDDA3P3), U2.19 (VDD3P3_RTC), U2.37 (VDD3P3_CPU), U2.43 (VDDA), U2.46 (VDDA); also elsewhere on the board
/ANT_RF: AE1.1 (A), U2.2 (LNA_IN)
/VMOTOR: C1.1, D1.1 (K), D9.1 (K), M1.1 (+)
ACC_INT1: U1.11 (INT1), U2.17 (IO14)
ACC_INT2: U1.9 (INT2), U2.10 (IO34)
ADC_BATT: R5.2, R6.1, U2.13 (IO33)
BUSY: J2.16, U2.38 (IO19)
DC: J2.14, U2.29 (SD3/IO10)
EN: C17.1, R12.2, U2.9 (EN); also elsewhere on the board
GDR: J2.23, Q4.1 (G), R9.1
GND: AE1.2 (Shield), C2.2, C3.1, C4.2, C5.2, C7.2, C9.2, C10.2, C11.2, C12.2, C13.2, C14.2, C15.2, C17.2, C25.2, C26.2, C27.2, C30.2, D3.1 (K), J1.6, J2.8, J2.17, Q1.2 (S), Q2.2 (E), R4.1, R6.2, R9.2, R10.1, R25.2, U1.5 (GND), U1.10 (GND), U1.12 (GND), U2.49 (GND), Y1.4 (CLKOE), Y1.5 (VSS); also elsewhere on the board
GPIO0: U2.23 (IO0); also elsewhere on the board
INT_TOUCH: J1.3, U2.11 (IO35)
MOSI: J2.11, U2.36 (IO23)
unnamed: C1.2, D1.2 (A), M1.2 (-), Q2.3 (C)
unnamed: C6.1, D2.1 (K), D3.2 (A)
unnamed: C6.2, D4.2 (A), L1.1, Q4.3 (D)
unnamed: C25.1, D8.2 (A), J1.4, R11.1, R28.1
unnamed: C14.1, J2.1
unnamed: C12.1, J2.3
unnamed: C11.1, J2.5
unnamed: C10.1, J2.7
unnamed: C15.1, J2.20
unnamed: Q1.3 (D), Q3.1 (G), R3.1
unnamed: Q2.1 (B), R2.1, R25.1
unnamed: Q3.3 (D), R5.1
unnamed: R1.1, U1.8 (CS)
unnamed: C30.1, U2.26 (VDD_SDIO)
PREVGH: C7.1, D4.1 (K), J2.4
PREVGL: C13.1, D2.2 (A), J2.2
PWR_BTN: U2.14 (IO25); also elsewhere on the board
RES: J2.15, U2.28 (SD2/IO9)
RESE: J2.22, Q4.2 (S), R10.2
RES_TOUCH_CTRL: R11.2, R28.2, U2.24 (IO4)
RTC_EVI: R21.2, TP1.1 (1_1), Y1.7 (EVI)
RTC_INT: R22.2, U2.16 (IO27), Y1.6 (~INT)
RX: U2.40 (U0RXD/IO3); also elsewhere on the board
SCK: J2.12, U2.35 (IO18)
SCL: J1.1, R7.2, U1.4 (SPC), U2.39 (IO22), Y1.8 (SCL)
SDA: J1.2, R8.2, U1.6 (SDI), U2.42 (IO21), Y1.1 (SDA)
SS: J2.13, U2.34 (IO5)
TX: U2.41 (U0TXD/IO1); also elsewhere on the board
VBAT_RAW: C2.1, Q3.2 (S), R3.2, R21.1, Y1.3 (VDD); also elsewhere on the board
VBAT_SENSE_EN: Q1.1 (G), R4.2, U2.15 (IO26)
VSYS: D9.2 (A); also elsewhere on the board
Vibration_PWM: R2.2, U2.20 (IO13)

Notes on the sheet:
ACELERÓMETRO LIS3DH
C3/C4: desacoplo local de VDD/VDD_IO. Colocar junto a U1.1/U1.14.
MEDIDA DE BATERÍA: GPIO26 HIGH habilita el divisor; leer ADC_BATT y volver a LOW. Apagar antes de brownout repetido; fijar el umbral por medida.
RF: CONEXIÓN DIRECTA DE 50 Ω, DECISIÓN ACEPTADA. AE1=AN012400C00; pista corta, uniforme, sin vías y con retorno continuo. Sin red π: no se montan valores de adaptación sin medida RF. Una revisión futura puede añadirla y ajustarla con VNA.
CONECTOR TÁCTIL FT6336U
MOTOR CANDIDATO: 3 V y 70 mA nominales. Verificar la corriente de arranque del lote antes de fabricar. https://es.aliexpress.com/item/1005007550657082.html
VELOCIDAD I²C: usar 100 kHz por defecto. Usar 400 kHz sólo tras validar los flancos con la PCB y el flex conectados.
RTC: Y1 usa VBAT_RAW para conservar la hora con el latch apagado. R22 lleva INT al dominio +3V3; no sustituirlo por un pull-up a VBAT_RAW. EVI no se usa: R21 la mantiene HIGH y TP1 permite recuperarla en el futuro.
DESACOPLO ESP32-PICO-D4: C27 absorbe ruido de alta frecuencia y debe quedar pegado a U2.1/3/4. C26 aporta reserva local; mantener cortos alimentación y retorno GND.
PANEL GDEY042T81-T02: https://buy-lcd.com/products/gdey042t81-t02
MOTOR DE 3 V: D9 reduce VSYS para no aplicarle hasta 4,2 V. GPIO13: LOW=OFF, HIGH=ON; PWM sólo para regular intensidad.
BOOSTER DEL PANEL: Este bloque sigue la aplicación específica GDEY042T81-T02, no la genérica del SSD1683. R9 es el pull-down de GDR; C8 y C16 se omiten porque sus pines son NC/prueba.
RESET FT6336U: C25 retrasa unos 30 ms; D8 descarga el nodo al apagar. GPIO4: open-drain LOW >=60 ms y después alta impedancia. Esperar >=300 ms antes de usar I²C.

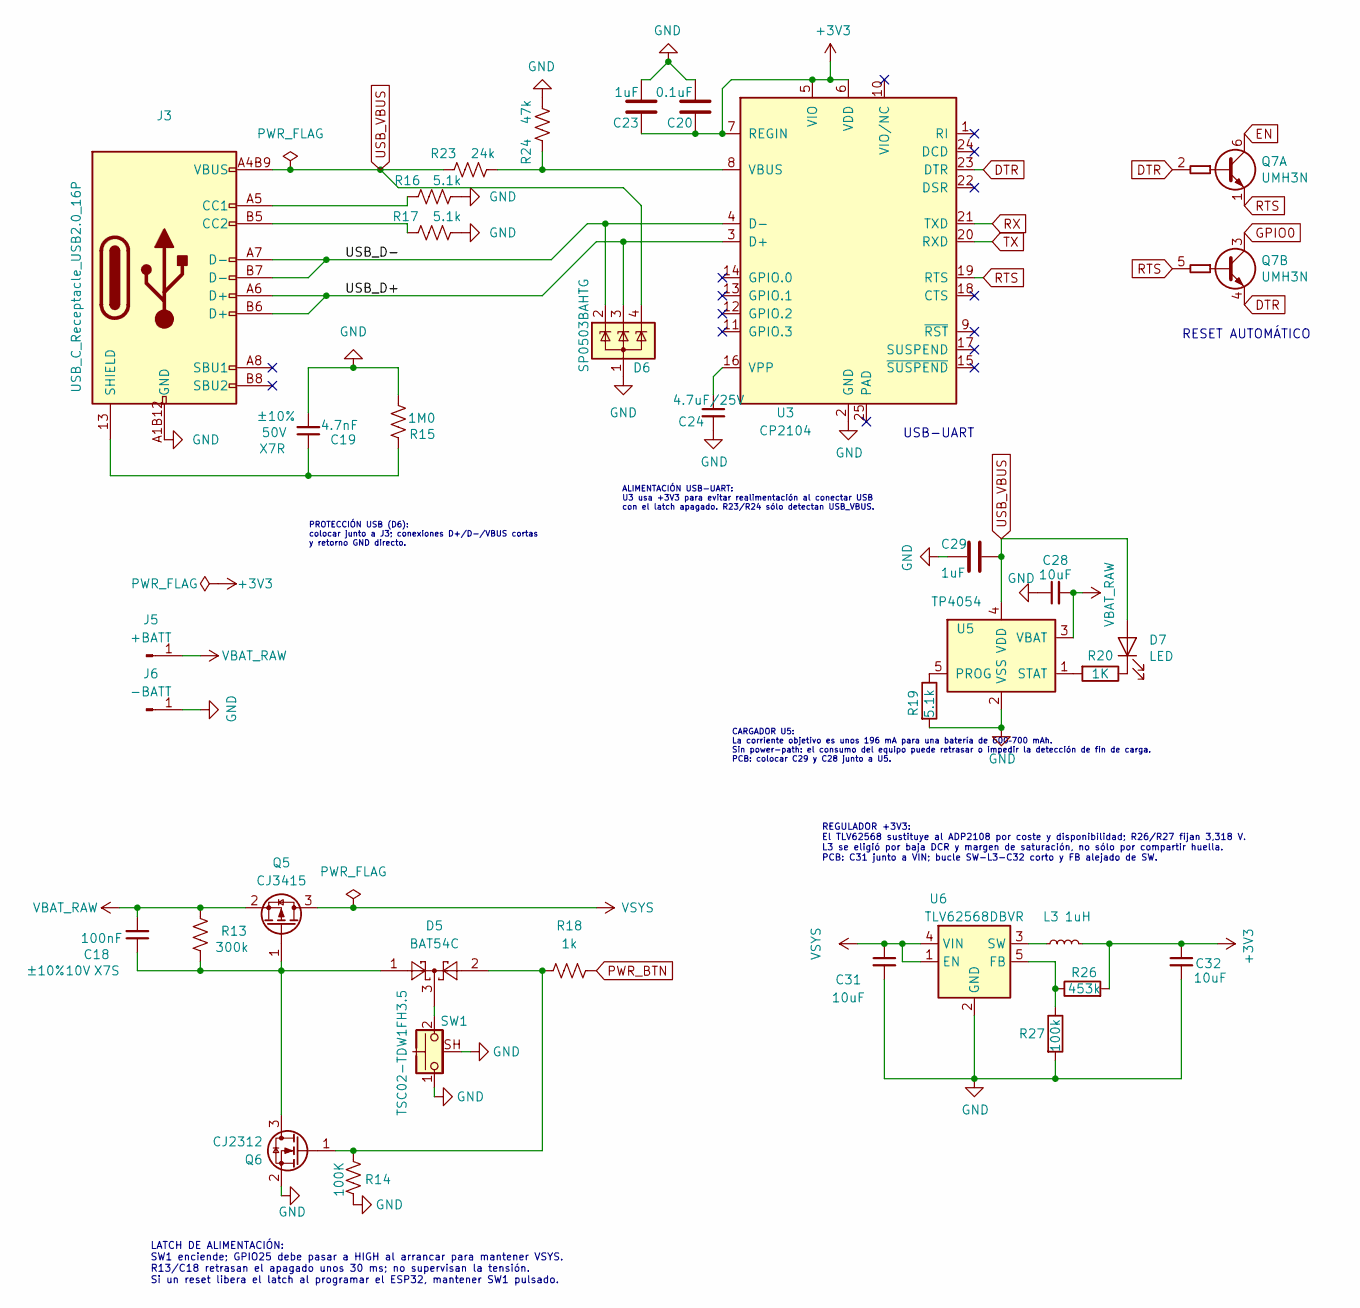
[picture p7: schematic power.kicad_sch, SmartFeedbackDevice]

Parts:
C18: 100nF; C_0402_1005Metric; Tolerance ±10%; Voltage_Rated 10V; LCSC Part # C1525
C19: 4.7nF; C_0603_1608Metric; Tolerance ±10%; Voltage_Rated 50V; LCSC Part # C53987
C20: 0.1uF; C_0603_1608Metric; LCSC Part # C14663
C23, C29: 1uF; C_0603_1608Metric; LCSC Part # C15849
C24: 4.7uF/25V; C_0603_1608Metric; LCSC Part # C69335
C28, C31, C32: 10uF; C_0603_1608Metric; LCSC Part # C19702
D5: BAT54C; SOT-23; LCSC Part # C22466350
D6: SP0503BAHTG; SOT-143; LCSC Part # C3040626
D7: LED; LED_1206_3216Metric_Pad1.42x1.75mm_HandSolder; LCSC Part # C84270
J3: USB_C_Receptacle_USB2.0_16P; USB-C-SMD_TYPE-C-16PIN-2MD-073; LCSC Part # C2765186
J5: +BATT; SolderWirePad_1x01_SMD_3x6mm
J6: -BATT; SolderWirePad_1x01_SMD_3x6mm
L3: 1uH; L_Changjiang_FTC252012S; MPN FTC252012S1R0MBCA; LCSC Part # C5832370
Q5: CJ3415; SOT-23; LCSC Part # C2910186
Q6: CJ2312; SOT-23; LCSC Part # C23521
Q7: UMH3N; SOT-363_SC-70-6; LCSC Part # C62892
R13: 300k; R_0603_1608Metric; LCSC Part # C23024
R14: 100K; R_0603_1608Metric; LCSC Part # C25803
R15: 1M0; R_0603_1608Metric; LCSC Part # C22935
R16, R17, R19: 5.1k; R_0603_1608Metric; LCSC Part # C23186
R18: 1k; R_0603_1608Metric; LCSC Part # C21190
R20: 1K; R_0603_1608Metric; LCSC Part # C21190
R23: 24k; R_0603_1608Metric; LCSC Part # C23352
R24: 47k; R_0603_1608Metric; LCSC Part # C25819
R26: 453k; R_0603_1608Metric; MPN RT0603BRD07453KL; LCSC Part # C861412
R27: 100k; R_0603_1608Metric; LCSC Part # C25803
SW1: TSC02-TDW1FH3.5; SW-SMD_L7.8-W3.5-P4.20-EH; LCSC Part # C22362983
U3: CP2104; QFN-24-1EP_4x4mm_P0.5mm_EP2.6x2.6mm; LCSC Part # C47742
U5: TP4054; SOT-23-5; LCSC Part # C5381776
U6: TLV62568DBVR; SOT-23-5; MPN TLV62568DBVR; LCSC Part # C163219

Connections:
+3V3: C20.1, C23.1, C32.1, L3.2, R26.2, U3.5 (VIO), U3.6 (VDD), U3.7 (REGIN); also elsewhere on the board
/Power/USB_D+: D6.3 (K), J3.A6 (D+), J3.B6 (D+), U3.3 (D+)
/Power/USB_D-: D6.2 (K), J3.A7 (D-), J3.B7 (D-), U3.4 (D-)
DTR: Q7.2 (B1), Q7.4 (E2), U3.23 (DTR)
EN: Q7.6 (C1); also elsewhere on the board
GND: C19.2, C20.2, C23.2, C24.2, C28.1, C29.2, C31.2, C32.2, D6.1 (A), J3.A1B12 (GND), J3.B1A12 (GND), J6.1 (Pin_1_1), Q6.2 (S), R14.2, R15.2, R16.2, R17.2, R19.2, R24.2, R27.2, SW1.1, SW1.SH (B), U3.2 (GND), U5.2 (VSS), U6.2 (GND); also elsewhere on the board
GPIO0: Q7.3 (C2); also elsewhere on the board
unnamed: D5.3, SW1.2
unnamed: D7.1 (K), R20.1
unnamed: J3.A5 (CC1), R16.1
unnamed: J3.B5 (CC2), R17.1
unnamed: C19.1, J3.13 (SHIELD), J3.14 (GND), R15.1
unnamed: C18.1, D5.1, Q5.1 (G), Q6.3 (D), R13.2
unnamed: D5.2, Q6.1 (G), R14.1, R18.1
unnamed: R23.2, R24.1, U3.8 (VBUS)
unnamed: C24.1, U3.16 (VPP)
unnamed: R19.1, U5.5 (PROG)
unnamed: R20.2, U5.1 (STAT)
unnamed: R26.1, R27.1, U6.5 (FB)
unnamed: L3.1, U6.3 (SW)
PWR_BTN: R18.2; also elsewhere on the board
RTS: Q7.1 (E1), Q7.5 (B2), U3.19 (RTS)
RX: U3.21 (TXD); also elsewhere on the board
TX: U3.20 (RXD); also elsewhere on the board
USB_VBUS: C29.1, D6.4 (K), D7.2 (A), J3.A4B9 (VBUS), J3.B4A9 (VBUS), R23.1, U5.4 (VDD)
VBAT_RAW: C18.2, C28.2, J5.1 (Pin_1_1), Q5.2 (S), R13.1, U5.3 (VBAT); also elsewhere on the board
VSYS: C31.1, Q5.3 (D), U6.1 (EN), U6.4 (VIN); also elsewhere on the board

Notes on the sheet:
RESET AUTOMÁTICO
ALIMENTACIÓN USB-UART: U3 usa +3V3 para evitar realimentación al conectar USB con el latch apagado. R23/R24 sólo detectan USB_VBUS.
USB-UART
PROTECCIÓN USB (D6): colocar junto a J3; conexiones D+/D-/VBUS cortas y retorno GND directo.
LATCH DE ALIMENTACIÓN: SW1 enciende; GPIO25 debe pasar a HIGH al arrancar para mantener VSYS. R13/C18 retrasan el apagado unos 30 ms; no supervisan la tensión. Si un reset libera el latch al programar el ESP32, mantener SW1 pulsado.
REGULADOR +3V3: El TLV62568 sustituye al ADP2108 por coste y disponibilidad; R26/R27 fijan 3,318 V. L3 se eligió por baja DCR y margen de saturación, no sólo por compartir huella. PCB: C31 junto a VIN; bucle SW-L3-C32 corto y FB alejado de SW.
CARGADOR U5: La corriente objetivo es unos 196 mA para una batería de 600–700 mAh. Sin power-path: el consumo del equipo puede retrasar o impedir la detección de fin de carga. PCB: colocar C29 y C28 junto a U5.

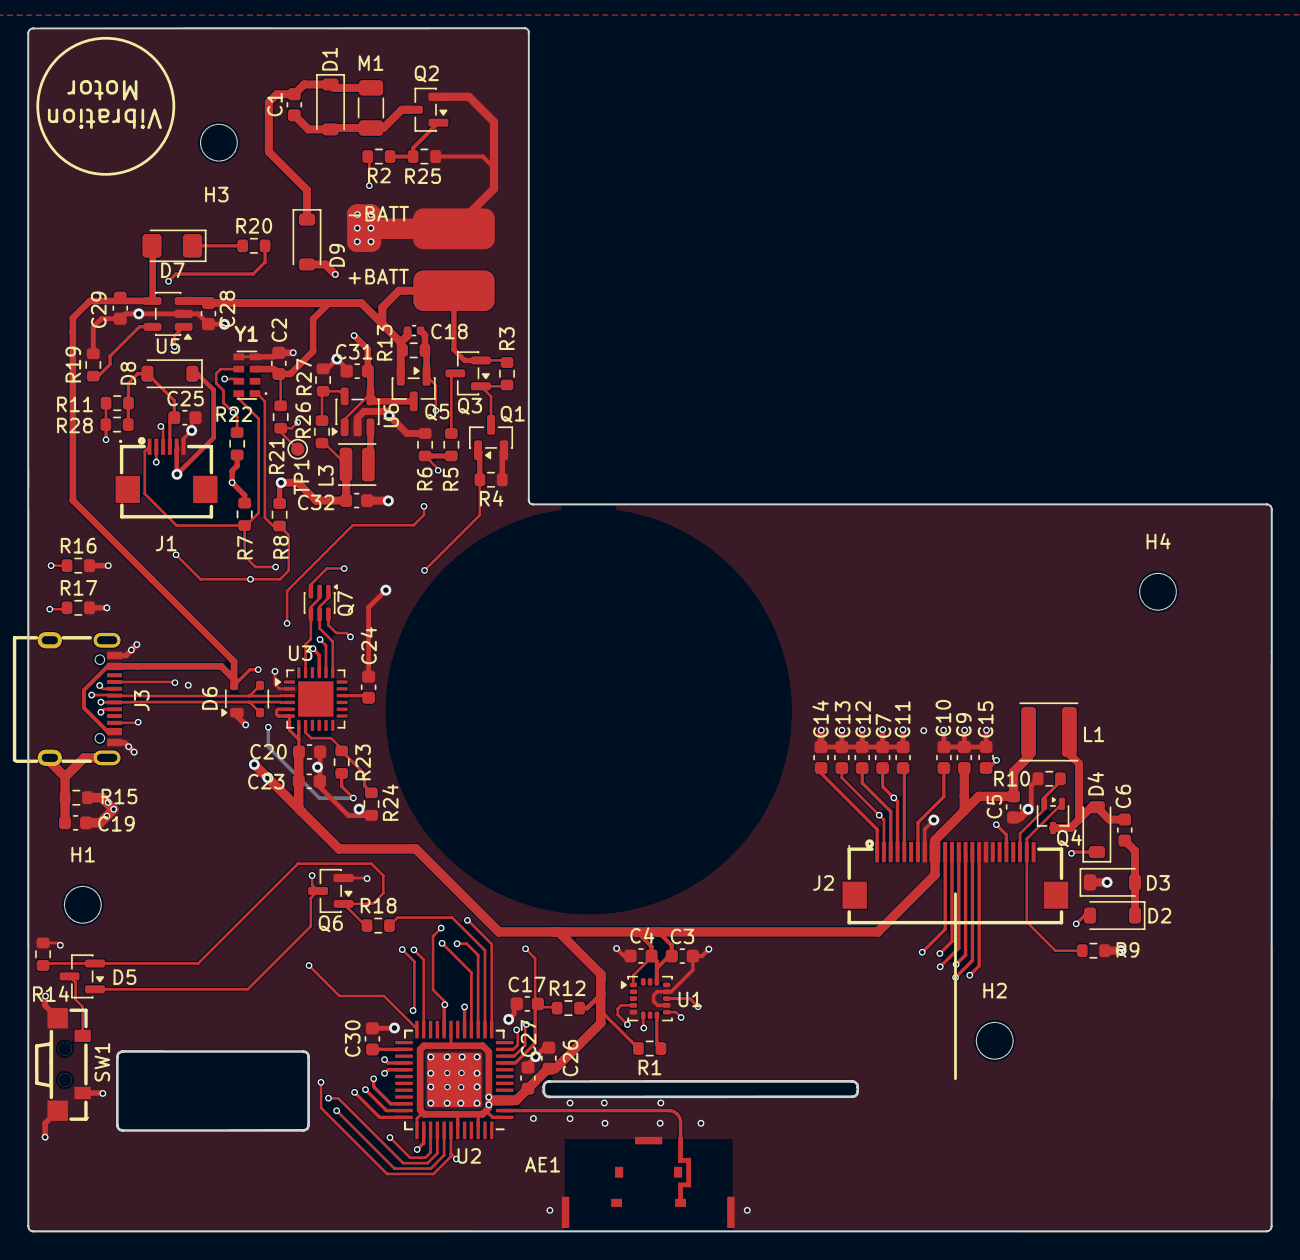
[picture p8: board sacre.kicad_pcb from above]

Board: 4 copper layers, 91.4 x 88.4 mm, 93 parts (0 on the bottom side), 64 nets.

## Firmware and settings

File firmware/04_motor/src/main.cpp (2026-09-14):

#include "board.h"
constexpr uint8_t CHANNEL = 0;
bool running = false;
uint32_t started = 0, stopped = 0;

void stopMotor() {
  ledcWrite(CHANNEL, 0);
  running = false;
  stopped = millis();
  Serial.println("Motor OFF.");
}

void setup() {
  Board::begin("motor");
  ledcSetup(CHANNEL, 20000, 8);
  ledcAttachPin(Pins::MOTOR, CHANNEL);
  ledcWrite(CHANNEL, 0);
  Serial.println("1/2/3: pulso 200 ms a 25/50/100%; 0: parar. Reposo 2 s.");
  Serial.println("PWM no limita la corriente de arranque. Confirmar motor del BOM.");
}

void loop() {
  // Stop PWM BEFORE common powerOff (digitalWrite cannot override LEDC).
  if (Serial.available() && Serial.peek() == 'x') stopMotor();
  const int c = Board::command();
  if (running && millis() - started >= 200) stopMotor();
  if (c == '0') stopMotor();
  if (c >= '1' && c <= '3') {
    if (running || millis() - stopped < 2000) {
      Serial.println("Esperar 2 s con motor parado.");
    } else {
      const uint8_t duty = c == '1' ? 64 : c == '2' ? 128 : 255;
      started = millis();
      running = true;
      ledcWrite(CHANNEL, duty);
      Serial.printf("Motor PWM=%u/255 por 200 ms.\n", duty);
    }
  }
  delay(1);
}

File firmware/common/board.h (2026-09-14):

#pragma once
#include <Arduino.h>
#include <esp_system.h>

// GPIO numbers, NOT package pin numbers. Checked against sacre.kicad_sch
// netlist and PCB on 2026-09-14. ESP32-PICO-D4; GPIO16 is internal flash.
namespace Pins {
constexpr uint8_t LATCH = 25;
constexpr uint8_t MOTOR = 13;
constexpr uint8_t BAT_ENABLE = 26;
constexpr uint8_t BAT_ADC = 33;
constexpr uint8_t SDA = 21, SCL = 22;
constexpr uint8_t TOUCH_RESET = 4, TOUCH_INT = 35;
constexpr uint8_t ACC_INT1 = 14, ACC_INT2 = 34;
constexpr uint8_t RTC_INT = 27;
constexpr uint8_t EPD_CS = 5, EPD_DC = 10, EPD_RESET = 9;
constexpr uint8_t EPD_BUSY = 19, EPD_SCK = 18, EPD_MOSI = 23;
}

namespace Board {
inline void begin(const char* test) {
  // First app action: self-hold, before Serial, I2C, SPI or radio.
  digitalWrite(Pins::LATCH, HIGH);
  pinMode(Pins::LATCH, OUTPUT);
  digitalWrite(Pins::MOTOR, LOW);
  pinMode(Pins::MOTOR, OUTPUT);
  digitalWrite(Pins::BAT_ENABLE, LOW);
  pinMode(Pins::BAT_ENABLE, OUTPUT);
  // Release touch reset; the external RC supplies the high level.
  pinMode(Pins::TOUCH_RESET, INPUT);
  digitalWrite(Pins::EPD_CS, HIGH);
  pinMode(Pins::EPD_CS, OUTPUT);
  Serial.begin(115200);
  delay(200);
  Serial.printf("\nSAcre / %s / reset reason=%d\n", test, int(esp_reset_reason()));
  Serial.println("GPIO25 HIGH. x: apagar (soltar antes el boton).");
}

[[noreturn]] inline void powerOff() {
  digitalWrite(Pins::MOTOR, LOW);
  digitalWrite(Pins::BAT_ENABLE, LOW);
  Serial.println("Apagando. Si sigue encendida, soltar el boton.");
  Serial.flush();
  digitalWrite(Pins::LATCH, LOW);
  for (;;) delay(1000); // Do not restart/reassert the latch if power persists.
}

inline int command() {
  if (!Serial.available()) return -1;
  const int c = Serial.read();
  if (c == 'x') powerOff();
  return c;
}

[[noreturn]] inline void fail(const char* message) {
  Serial.printf("ERROR: %s. Corregir y reiniciar; x: apagar.\n", message);
  for (;;) { command(); delay(10); }
}
}

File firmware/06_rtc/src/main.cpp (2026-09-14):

#include "i2c_io.h"
#include <cstring>
constexpr uint8_t ADDRESS = 0x32;
constexpr uint8_t EXT = 0x0d, FLAGS = 0x0e, CONTROL = 0x0f;
constexpr uint8_t AF = 0x08, AIE = 0x08, V2F = 0x02;
uint8_t bcd(int value) { return uint8_t((value / 10) * 16 + value % 10); }
int decimal(uint8_t value) { return (value >> 4) * 10 + (value & 15); }
bool validBcd(uint8_t value, int low, int high) {
  return (value & 15) <= 9 && (value >> 4) <= 9 && decimal(value) >= low && decimal(value) <= high;
}

bool readTime(uint8_t* data) {
  if (!I2C::read(ADDRESS, 0x00, data, 7)) return false;
  return validBcd(data[0], 0, 59) && validBcd(data[1], 0, 59) &&
         validBcd(data[2], 0, 23) && validBcd(data[4], 1, 31) &&
         validBcd(data[5], 1, 12) && validBcd(data[6], 0, 99);
}

bool cancelAlarm() {
  uint8_t control;
  if (!I2C::readByte(ADDRESS, CONTROL, control)) return false;
  if (!I2C::writeByte(ADDRESS, CONTROL, control & ~AIE)) return false;
  // Writing 1 leaves other flags unchanged, including low-voltage evidence.
  return I2C::writeByte(ADDRESS, FLAGS, 0x3f & ~AF);
}

bool setBuildTime() {
  char monthName[4];
  int day, year, hour, minute, second;
  if (sscanf(__DATE__, "%3s %d %d", monthName, &day, &year) != 3 ||
      sscanf(__TIME__, "%d:%d:%d", &hour, &minute, &second) != 3) return false;
  const char* months = "JanFebMarAprMayJunJulAugSepOctNovDec";
  const char* pos = strstr(months, monthName);
  if (!pos) return false;
  const int month = (pos - months) / 3 + 1;
  const int offsets[] = {0, 3, 2, 5, 0, 3, 5, 1, 4, 6, 2, 4};
  const int y = year - (month < 3);
  const int weekday = (y + y/4 - y/100 + y/400 + offsets[month-1] + day) % 7;
  const uint8_t time[] = {bcd(second), bcd(minute), bcd(hour), uint8_t(1 << weekday),
                          bcd(day), bcd(month), bcd(year % 100)};
  if (!I2C::writeByte(ADDRESS, CONTROL, 0x01)) {
    I2C::writeByte(ADDRESS, CONTROL, 0x00); // A failed readback may follow an accepted write.
    return false;
  }
  // Explicit command t resets the writable configuration, including offset.
  // Required after V2F/POR; never performed automatically on ESP32 reset.
  const uint8_t settings[] = {0x80, 0x80, 0x80, 0, 0, 0}; // 08h..0Dh
  bool ok = I2C::write(ADDRESS, 0x08, settings, sizeof(settings)) &&
            I2C::writeByte(ADDRESS, 0x2c, 0) &&
            I2C::writeByte(ADDRESS, 0x2f, 0) &&
            I2C::write(ADDRESS, 0x00, time, sizeof(time));
  const bool resumed = I2C::writeByte(ADDRESS, CONTROL, 0);
  if (!ok || !resumed) return false;
  return I2C::writeByte(ADDRESS, FLAGS, 0); // Clear invalid-time flags only after successful init.
}

bool armAlarm() {
  uint8_t data[7], flags, control, ext;
  if (!readTime(data) || !I2C::readByte(ADDRESS, FLAGS, flags) || (flags & V2F) ||
      !I2C::readByte(ADDRESS, CONTROL, control) || (control & 1) ||
      !I2C::readByte(ADDRESS, EXT, ext)) return false;
  if (!cancelAlarm()) return false;
  const int next = (decimal(data[2]) * 60 + decimal(data[1]) + 1) % (24 * 60);
  const uint8_t alarm[] = {bcd(next % 60), bcd(next / 60), 0x80};
  // Disable other interrupt sources so GPIO27 proves the alarm specifically.
  if (!I2C::writeByte(ADDRESS, CONTROL, 0) ||
      !I2C::writeByte(ADDRESS, EXT, ext & 0x0f) ||
      !I2C::write(ADDRESS, 0x08, alarm, sizeof(alarm)) ||
      !I2C::writeByte(ADDRESS, FLAGS, 0x3f & ~AF) ||
      !I2C::writeByte(ADDRESS, CONTROL, AIE)) return false;
  Serial.printf("Alarma a las %02d:%02d (proximo minuto); GPIO27 debe bajar.\n", next/60, next%60);
  return true;
}

void setup() {
  Board::begin("RTC RV-8803-C7");
  I2C::begin();
  pinMode(Pins::RTC_INT, INPUT); // R22 supplies the external pull-up.
  uint8_t flags;
  if (!I2C::readByte(ADDRESS, FLAGS, flags)) Board::fail("RTC ausente/no responde (montaje opcional)");
  Serial.println("Lectura sin cambiar hora. t: inicializar a fecha/hora de compilacion.");
  Serial.println("a: alarma proximo minuto; c: cancelar/limpiar alarma; x: apagar.");
  Serial.printf("Compilado: %s %s; flags iniciales=0x%02X\n", __DATE__, __TIME__, flags);
}

void loop() {
  const int c = Board::command();
  if (c == 't') Serial.println(setBuildTime() ? "Hora/configuracion inicializadas." : "ERROR al ajustar RTC.");
  if (c == 'a' && !armAlarm()) Serial.println("ERROR alarma; comprobar hora valida (t) e I2C.");
  if (c == 'c') Serial.println(cancelAlarm() ? "Alarma cancelada." : "ERROR cancelando alarma.");
  static uint32_t lastRead = 0;
  if (millis() - lastRead >= 1000) {
    lastRead = millis();
    uint8_t data[7], flags, control;
    if (!I2C::readByte(ADDRESS, FLAGS, flags) || !I2C::readByte(ADDRESS, CONTROL, control)) {
      Serial.println("ERROR I2C RTC"); return;
    }
    if (!readTime(data) || (flags & V2F) || (control & 1)) {
      Serial.printf("Hora NO valida/parada; flags=0x%02X control=0x%02X; t: inicializar.\n", flags, control);
      return;
    }
    Serial.printf("20%02d-%02d-%02d %02d:%02d:%02d flags=0x%02X INT=%d AF=%d\n",
                  decimal(data[6]), decimal(data[5]), decimal(data[4]), decimal(data[2]),
                  decimal(data[1]), decimal(data[0]), flags, digitalRead(Pins::RTC_INT), bool(flags & AF));
    // Leave AF latched for inspection. User clears it with c.
  }
  delay(5);
}

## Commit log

2026-05-08 Clean KiCad project files
    [EDI2CAP.CFG, EVQ-PUA02K.SchLib, EVQ-PUA02K.stp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]
2026-05-08 Fix KiCad schematic symbol name
    [sacre.kicad_sch, sacre.sch]
2026-05-09 nuevas features: USB C, boton encendido, conector touch,sin botones, sin NFC
    [power.kicad_sch, sacre.kicad_pcb, sacre.kicad_sch]
2026-05-12 se fini
    [power.kicad_sch, sacre.kicad_pcb, sacre.kicad_sch]
2026-05-13 agujeros tornillos
    [sacre.kicad_pcb]
2026-07-29 Guarda el estado actual del diseño KiCad
    [sacre.kicad_pcb, sacre.kicad_sch]
2026-07-29 Documenta la revisión posterior a fabricación
    [bom.xls, bom_jlcpb.csv]
2026-07-29 Corrige SDA y SCL del conector táctil
    [sacre.kicad_pcb, sacre.kicad_sch]
2026-08-03 Consolida correcciones eléctricas y documentación
    [power.kicad_sch, sacre.kicad_pcb, sacre.kicad_sch]
2026-09-13 Aclara notas del esquema y valida salida de 3V3
    [power.kicad_sch, sacre.kicad_sch]
2026-09-13 Guarda referencia visual y alcance de preparacion PCB
2026-09-13 Sincroniza PCB con esquema: componentes huellas y redes
    [sacre.kicad_pcb]
2026-09-13 Retira cobre obsoleto y ramas sin destino tras sincronizacion
    [sacre.kicad_pcb]
2026-09-13 Coloca componentes por zonas y deja PCB preparada para enrutar
    [sacre.kicad_pcb]
2026-09-13 Guarda PCB enrutada y revisada con reglas JLCPCB y correccion de J3
    [sacre.kicad_pcb]
2026-09-14 Cierra revision PCB y prepara pedido JLCPCB
    [sacre.kicad_pcb, sacre.kicad_sch]
2026-09-14 Añade ocho pruebas de firmware independientes para SAcre
